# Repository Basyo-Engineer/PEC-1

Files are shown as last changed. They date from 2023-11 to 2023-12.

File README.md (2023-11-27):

# PEC-1
Hand made 8bitCPU, Prototype Experimental Computer No.1

## Picture
動いている様子．下記のSample Codeを動かしています．

F-tropnacAAZ7CA

## CPU Architecture

CPU Architecture drawio

## Command List
PEC-1で使用可能なコマンド一覧です．

GRx,GRyは汎用レジスタです．ImはImmidiate Data，すなわち即値データです．

スクリーンショット 2023-11-12 145332

## Machine Code
コマンドのマシン語対応表です．

xxやyyは，コマンドで指定したいレジスタ番号の二進数表示です．00(0)～11(3)番まで行けます．

[imdt]は即値データです．データ長は6bitです．

基本的に，オペコード部で各部の制御を行っています．なので，
ジャンプ命令などは仕様上レジスタの指定は冗長と扱うためオペランドはどう書いても問題ありません．
また，即値が「000000」となっているコマンドも，即値の入力は冗長です，

スクリーンショット 2023-11-12 145337

## Sample Code
サンプルコードです．掛け算と引き算を行うプログラムです．

スクリーンショット 2023-11-12 145524

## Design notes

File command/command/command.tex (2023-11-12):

\documentclass[lualatex,js=standard,hiresbb,openany]{bxjsarticle}
\usepackage{luatexja}
\usepackage{geometry}
\geometry{margin=5mm}

%数式
\usepackage{amsmath,amsfonts}
\usepackage{bm}
\usepackage{siunitx}
\usepackage{ulem}

%画像
\usepackage[dvipdfmx]{graphicx}
\usepackage{color}
\usepackage{subfigure}
\usepackage{float}
\usepackage{caption}
\usepackage{comment}

%枠付き文章
\usepackage{ascmac}

%章=chapter, 節=section, 小節=subseciton, 小小節=subsubsection
\begin{document}

\begin{table}[H]
 \begin{center}
  \begin{tabular}{cll}\hline
    命令種類 & ニーモニック & 説明 \\ 
    \hline \hline
    転送     & MOV  $\mathrm{GRx}$, $\mathrm{GRy}$        & $\mathrm{GRx}$ <- $\mathrm{GRy}$ \\ 
    転送     & MOV  $\mathrm{GRx}$, Im                    & $\mathrm{GRx}$ <- (Im)\\
    算術     & ADD  $\mathrm{GRx}$, $\mathrm{GRy}$        & $\mathrm{GRx}$ <- $\mathrm{GRx}$ + $\mathrm{GRy}$ \\ 
    算術     & ADD  $\mathrm{GRx}$, Im                    & $\mathrm{GRx}$ <- $\mathrm{GRx}$ + (Im) \\
    算術     & SUB  $\mathrm{GRx}$, $\mathrm{GRy}$        & $\mathrm{GRx}$ <- $\mathrm{GRx}$ - $\mathrm{GRy}$\\ 
    算術     & SUB  $\mathrm{GRx}$, Im                    & $\mathrm{GRx}$ <- $\mathrm{GRx}$ - (Im) \\
    論理     & NAND $\mathrm{GRx}$, $\mathrm{GRy}$        & $\mathrm{GRx}$ <- $\overline{\mathrm{GRx \cdot GRy}}$ \\
    論理     & NAND $\mathrm{GRx}$, Im                    & $\mathrm{GRx}$ <- $\overline{\mathrm{GRx \cdot Im}}$ \\
    条件分岐 & JMP  Im                                    & jump (Im) \\
    条件分岐 & JNO  Im                                    & jump (Im) if OverFlow Flag = 0 \\
    条件分岐 & JZE  Im                                    & jump (Im) if Zero Flag = 1 \\
    条件分岐 & JMI  Im                                    & jump (Im) if Sign Flag = 1\\
    条件分岐 & JPL  Im                                    & jump (Im) if Sign Flag = 0 \& Zero Flag = 0 \\
    その他   & IN   $\mathrm{GRx}$                        & $\mathrm{GRx}$ <- Input \\
    その他   & OUT  $\mathrm{GRx}$                        & $\mathrm{GRx}$ -> Output \\
    その他   & NOP                                        & なにもしない \\
     \hline
  \end{tabular}
  \label{tab:}
 \end{center}
\end{table}

\begin{table}[H]
 \begin{center}
  \begin{tabular}{lcccc}\hline
    命令                                & オペコード & オペランド1 & オペランド2 & 即値\\
    \hline \hline 
    MOV  $\mathrm{GRx}$, $\mathrm{GRy}$ &   0010    &   xx   &   yy   &    000000 \\
    MOV  $\mathrm{GRx}$, Im             &   0011    &   xx   &   00   &    [imdt] \\
    ADD  $\mathrm{GRx}$, $\mathrm{GRy}$ &   0100    &   xx   &   yy   &    000000 \\
    ADD  $\mathrm{GRx}$, Im             &   0101    &   xx   &   00   &    [imdt] \\
    SUB  $\mathrm{GRx}$, $\mathrm{GRy}$ &   0110    &   xx   &   yy   &    000000 \\
    SUB  $\mathrm{GRx}$, Im             &   0111    &   xx   &   00   &    [imdt] \\
    NAND $\mathrm{GRx}$, $\mathrm{GRy}$ &   1000    &   xx   &   yy   &    000000 \\
    NAND $\mathrm{GRx}$, Im             &   1001    &   xx   &   00   &    [imdt] \\
    JMP  Im                             &   0001    &   00   &   00   &    [imdt] \\
    JNO  Im                             &   1011    &   00   &   00   &    [imdt] \\
    JZE  Im                             &   1010    &   00   &   00   &    [imdt] \\
    JMI  Im                             &   1100    &   00   &   00   &    [imdt] \\
    JPL  Im                             &   1101    &   00   &   00   &    [imdt] \\
    IN   $\mathrm{GRx}$                 &   1110    &   xx   &   00   &    000000 \\
    OUT  $\mathrm{GRx}$                 &   1111    &   xx   &   00   &    000000 \\
    NOP                                 &   0000    &   00   &   00   &    000000 \\  
    \hline                          
  \end{tabular}
  \label{tab:}
 \end{center}
\end{table}

\begin{comment}
0:gr0, 1:gr1, 2:gr2, 3:gr3, 4:inp, 5:[imdt], 6:000000

\begin{table}[H]
 \begin{center}
  \caption{null}
  \begin{tabular}{|cccc|cc|cc|ccc|cccccccc|}\hline
    \multicolumn{4}{|c|}{opecord} & \multicolumn{4}{c|}{operand} & \multicolumn{3}{c|}{flag} &  \multicolumn{8}{c|}{出力}\\ \hline 
    op3 & op2 & op1 & op0 & ora1 & ora0 & orb1 & orb0 & ZF & OF & SF & sela & selb & ld0 & ld1 & ld2 & ld3 & ldo & ldp c \\ \hline
    0   & 0   & 1   & 0   & x    & x    & y    & y    &  X &  X &  X &   yy &  110 &   x  &  x &   x &   x &  1  &   1  \\  \hline
    0   & 0   & 1   & 1   & x    & x    & 0    & 0    &  X &  X &  X &  101 &  110 &   x  &  x &   x &   x &  1  &   1  \\ \hline
    0   & 1   & 0   & 0   & x    & x    & y    & y    &  X &  X &  X &   xx &   yy &   x  &  x &   x &   x &  1  &   1  \\ \hline
    0   & 1   & 0   & 1   & x    & x    & 0    & 0    &  X &  X &  X &   xx &  101 &   x  &  x &   x &   x &  1  &   1  \\ \hline
    0   & 1   & 1   & 0   & x    & x    & y    & y    &  X &  X &  X &   xx &   yy &   x  &  x &   x &   x &  1  &   1  \\ \hline
    0   & 1   & 1   & 1   & x    & x    & 0    & 0    &  X &  X &  X &   xx &  101 &   x  &  x &   x &   x &  1  &   1  \\ \hline
    1   & 0   & 0   & 0   & x    & x    & y    & y    &  X &  X &  X &   xx &   yy &   x  &  x &   x &   x &  1  &   1  \\ \hline
    1   & 0   & 0   & 1   & x    & x    & 0    & 0    &  X &  X &  X &   xx &  101 &   x  &  x &   x &   x &  1  &   1  \\ \hline
    0   & 0   & 0   & 1   & 0    & 0    & 0    & 0    &  X &  X &  X &  101 &  110 &   1  &  1 &   1 &   1 &  1  &   0  \\ \hline
    1   & 0   & 1   & 1   & 0    & 0    & 0    & 0    &  X &  0 &  X &  101 &  110 &   1  &  1 &   1 &   1 &  1  &   0  \\ \hline
    1   & 0   & 1   & 0   & 0    & 0    & 0    & 0    &  1 &  X &  X &  101 &  110 &   1  &  1 &   1 &   1 &  1  &   0  \\ \hline
    1   & 1   & 0   & 0   & 0    & 0    & 0    & 0    &  X &  X &  1 &  101 &  110 &   1  &  1 &   1 &   1 &  1  &   0  \\ \hline
    1   & 1   & 0   & 1   & 0    & 0    & 0    & 0    &  0 &  X &  0 &  101 &  110 &   1  &  1 &   1 &   1 &  1  &   0  \\ \hline
    1   & 1   & 1   & 0   & x    & x    & 0    & 0    &  X &  X &  X &  100 &  110 &   x  &  x &   x &   x &  1  &   1  \\ \hline
    1   & 1   & 1   & 1   & x    & x    & 0    & 0    &  X &  X &  X &   xx &  110 &   1  &  1 &   1 &   1 &  0  &   1  \\ \hline
    0   & 0   & 0   & 0   & 0    & 0    & 0    & 0    &  X &  X &  X &   00 &   00 &   1  &  1 &   1 &   1 &  1  &   1  \\ \hline
  \end{tabular}
  \label{tab:}
 \end{center}
\end{table}

\end{comment}

\end{document}

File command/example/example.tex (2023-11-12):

\documentclass[lualatex,js=standard,hiresbb,openany]{bxjsarticle}
\usepackage{luatexja}
\usepackage{geometry}
\geometry{margin=17mm}

%数式
\usepackage{amsmath,amsfonts}
\usepackage{bm}
\usepackage{siunitx}
\usepackage{ulem}
\usepackage{mathtools}

%画像
\usepackage[dvipdfmx]{graphicx}
\usepackage{color}
\usepackage{subfigure}
\usepackage{float}
\usepackage{caption}

%枠付き文章
\usepackage{ascmac}
\usepackage{comment}
\usepackage{url}

%松尾先生用
\begin{comment}
\usepackage{fancyhdr}
\pagestyle{fancy}
   \lhead{情報工学実験　第4章　デコーダおよび数字表示回路に関する実験}
   \chead{\empty} %ヘッダ中央
   \rhead{\empty} %ヘッダ右．コンパイルした日付を表示
   \lfoot{\empty} %フッタ左
   \cfoot{\thepage} %フッタ中央．ページ番号を表示
   \rfoot{\empty} %フッタ右
   \renewcommand{\headrulewidth}{0pt}

\end{comment}
\begin{document}

\center{掛け算プログラム(3 $\times$ 10と 4 $\times$ 3 を計算して，両結果を減算)}

\begin{table}[H]
  \begin{center}
   \begin{tabular}{lcccc}\hline
      アドレス & ニーモニック & マシンコード & コメント\\
      \hline \hline
      0 & MOV GR2, 0    & 0011 10 00 000000 & レジスタ2に0を代入\\
      1 & MOV GR0, 10   & 0011 00 00 001010 & レジスタ0に10を代入\\
      2 & SUB GR0, 0    & 0111 00 00 000000 & レジスタ0から0を減算\\
      3 & JZE at 7      & 1010 00 00 000010 & 前の計算結果でZero Flag = 1なら\\ &&&当該アドレスにジャンプ\\
      4 & ADD GR2, 3    & 0101 10 00 000011 & レジスタ2に3を加算\\
      5 & SUB GR0, 1    & 0111 00 00 000001 & レジスタ0から1を減算\\
      6 & JMP at 2      & 0001 00 00 000010 & 当該アドレスに強制ジャンプ\\
      7 & MOV GR3, 0    & 0011 11 00 000000 & レジスタ3に0を代入\\
      8 & MOV GR0, 3    & 0011 00 00 000011 & レジスタ0に3を代入\\
      9 & SUB GR0, 0    & 0111 00 00 000000 & レジスタ0から0を減算\\
     10 & JZE at 14     & 1010 00 00 001110 & 前の計算結果でZero Flag = 1なら\\ &&&当該アドレスにジャンプ\\
     11 & ADD GR3, 4    & 0101 11 00 000100 & レジスタ3に4を加算\\
     12 & SUB GR0, 1    & 0111 00 00 000001 & レジスタ0から1を減算\\
     13 & JMP at 9      & 0001 00 00 001001 & 当該アドレスに強制ジャンプ\\
     14 & SUB GR2, GR3  & 0110 10 11 000000 & GR2とGR3を減算 \\
     15 & MOV GR1, GR2  & 0010 01 10 000000 & GR1にGR2の値をコピー\\
     16 & OUT GR1       & 1111 01 00 000000 & 出力レジスタにGR1の値を出力\\
     17 & MOV GR0, 0    & 0011 00 00 000000 & レジスタ0に0を代入\\
     18 & MOV GR1, 0    & 0011 01 00 000000 & レジスタ1に0を代入\\
     19 & MOV GR2, 0    & 0011 10 00 000000 & レジスタ2に0を代入\\
     20 & MOV GR3, 0    & 0011 11 00 000000 & レジスタ3に0を代入\\
     21 & OUT GR0       & 1111 00 00 000000 & 出力レジスタにGR0の値を出力\\
     22 & JMP at 0      & 0001 00 00 000000 & 当該アドレスに強制ジャンプ\\

     \hline                          
   \end{tabular}
   \label{tab:}
  \end{center}
 \end{table}
 \newpage

 \center{符号付6bit 2進数対応表}
 \begin{table}[H]
  \begin{center}
   \begin{tabular}{|c|c|c|c|c|c|c|c|}\hline
      10進数 & 2進数 & & & 10進数 & 2進数 & & \\
      \hline
      0      & 000000 &  16 & 010000 0  &   -1      & 111111 &  -17 & 101111 \\
      1      & 000001 &  17 & 010001    &   -2      & 111110 &  -18 & 101110 \\     
      2      & 000010 &  18 & 010010    &   -3      & 111101 &  -19 & 101101 \\   
      3      & 000011 &  19 & 010011    &   -4      & 111100 &  -20 & 101100 \\   
      4      & 000100 &  20 & 010100    &   -5      & 111011 &  -21 & 101011 \\   
      5      & 000101 &  21 & 010101    &   -6      & 111010 &  -22 & 101010 \\   
      6      & 000110 &  22 & 010110    &   -7      & 111001 &  -23 & 101001 \\   
      7      & 000111 &  23 & 010111    &   -8      & 111000 &  -24 & 101000 \\   
      8      & 001000 &  24 & 011000    &   -9      & 110111 &  -25 & 100111 \\   
      9      & 001001 &  25 & 011001    &  -10      & 110110 &  -26 & 100110 \\   
     10      & 001010 &  26 & 011010    &  -11      & 110101 &  -27 & 100101 \\   
     11      & 001011 &  27 & 011011    &  -12      & 110100 &  -28 & 100100 \\   
     12      & 001100 &  28 & 011100    &  -13      & 110011 &  -29 & 100011 \\   
     13      & 001101 &  29 & 011101    &  -14      & 110010 &  -30 & 100010 \\   
     14      & 001110 &  30 & 011110    &  -15      & 110001 &  -31 & 100001 \\   
     15      & 001111 &  31 & 011111    &  -16      & 110000 &  -32 & 100000 \\   
     \hline
   \end{tabular}
   \label{tab:}
  \end{center}
 \end{table}

\end{document}

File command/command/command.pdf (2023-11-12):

命令種類 ニーモニック | 説明
転送 | MOV GRx, GRy | GRx <- GRy
転送 | MOV GRx, Im | GRx <- (Im)
算術 | ADD GRx, GRy | GRx <- GRx + GRy
算術 | ADD GRx, Im | GRx <- GRx + (Im)
算術 | SUB GRx, GRy | GRx <- GRx - GRy
算術 | SUB GRx, Im | GRx <- GRx - (Im)
論理 | NAND GRx, GRy | GRx <- GRx · GRy
論理 | NAND GRx, Im | GRx <- GRx · Im
条件分岐 JMP Im | jump (Im)
条件分岐 JNO Im | jump (Im) if OverFlow Flag = 0
条件分岐 JZE Im | jump (Im) if Zero Flag = 1
条件分岐 JMI Im | jump (Im) if Sign Flag = 1
条件分岐 JPL Im | jump (Im) if Sign Flag = 0 & Zero Flag = 0
その他 | IN GRx | GRx <- Input
その他 | OUT GRx | GRx -> Output
その他 | NOP | なにもしない
命令 | オペコード オペランド 1 オペランド 2 | 即値
MOV GRx, GRy | 0010 | xx | yy | 000000
MOV GRx, Im | 0011 | xx | 00 | [imdt]
ADD GRx, GRy | 0100 | xx | yy | 000000
ADD GRx, Im | 0101 | xx | 00 | [imdt]
SUB GRx, GRy | 0110 | xx | yy | 000000
SUB GRx, Im | 0111 | xx | 00 | [imdt]
NAND GRx, GRy | 1000 | xx | yy | 000000
NAND GRx, Im | 1001 | xx | 00 | [imdt]
JMP Im | 0001 | 00 | 00 | [imdt]
JNO Im | 1011 | 00 | 00 | [imdt]
JZE Im | 1010 | 00 | 00 | [imdt]
JMI Im | 1100 | 00 | 00 | [imdt]
JPL Im | 1101 | 00 | 00 | [imdt]
IN GRx | 1110 | xx | 00 | 000000
OUT GRx | 1111 | xx | 00 | 000000
NOP | 0000 | 00 | 00 | 000000

1

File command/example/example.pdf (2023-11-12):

掛け算プログラム (3 × 10 と 4 × 3 を計算して，両結果を減算)

アドレス | ニーモニック | マシンコード | コメント
0 | MOV GR2, 0 | 0011 10 00 000000 | レジスタ 2 に 0 を代入
1 | MOV GR0, 10 | 0011 00 00 001010 | レジスタ 0 に 10 を代入
2 | SUB GR0, 0 | 0111 00 00 000000 | レジスタ 0 から 0 を減算
3 | JZE at 7 | 1010 00 00 000010 前の計算結果で Zero Flag = 1 なら
| | | 当該アドレスにジャンプ
4 | ADD GR2, 3 | 0101 10 00 000011 | レジスタ 2 に 3 を加算
5 | SUB GR0, 1 | 0111 00 00 000001 | レジスタ 0 から 1 を減算
6 | JMP at 2 | 0001 00 00 000010 | 当該アドレスに強制ジャンプ
7 | MOV GR3, 0 | 0011 11 00 000000 | レジスタ 3 に 0 を代入
8 | MOV GR0, 3 | 0011 00 00 000011 | レジスタ 0 に 3 を代入
9 | SUB GR0, 0 | 0111 00 00 000000 | レジスタ 0 から 0 を減算
10 | JZE at 14 | 1010 00 00 001110 前の計算結果で Zero Flag = 1 なら
| | | 当該アドレスにジャンプ
11 | ADD GR3, 4 | 0101 11 00 000100 | レジスタ 3 に 4 を加算
12 | SUB GR0, 1 | 0111 00 00 000001 | レジスタ 0 から 1 を減算
13 | JMP at 9 | 0001 00 00 001001 | 当該アドレスに強制ジャンプ
14 | SUB GR2, GR3 0110 10 11 000000 | GR2 と GR3 を減算
15 | MOV GR1, GR2 0010 01 10 000000 | GR1 に GR2 の値をコピー
16 | OUT GR1 | 1111 01 00 000000 | 出力レジスタに GR1 の値を出力
17 | MOV GR0, 0 | 0011 00 00 000000 | レジスタ 0 に 0 を代入
18 | MOV GR1, 0 | 0011 01 00 000000 | レジスタ 1 に 0 を代入
19 | MOV GR2, 0 | 0011 10 00 000000 | レジスタ 2 に 0 を代入
20 | MOV GR3, 0 | 0011 11 00 000000 | レジスタ 3 に 0 を代入
21 | OUT GR0 | 1111 00 00 000000 | 出力レジスタに GR0 の値を出力
22 | JMP at 0 | 0001 00 00 000000 | 当該アドレスに強制ジャンプ

1

符号付 6bit 2 進数対応表

10 進数 | 2 進数 | | | 10 進数 | 2 進数
0 | 000000 | 16 | 010000 0 | -1 | 111111 | -17 | 101111
1 | 000001 | 17 | 010001 | -2 | 111110 | -18 | 101110
2 | 000010 | 18 | 010010 | -3 | 111101 | -19 | 101101
3 | 000011 | 19 | 010011 | -4 | 111100 | -20 | 101100
4 | 000100 | 20 | 010100 | -5 | 111011 | -21 | 101011
5 | 000101 | 21 | 010101 | -6 | 111010 | -22 | 101010
6 | 000110 | 22 | 010110 | -7 | 111001 | -23 | 101001
7 | 000111 | 23 | 010111 | -8 | 111000 | -24 | 101000
8 | 001000 | 24 | 011000 | -9 | 110111 | -25 | 100111
9 | 001001 | 25 | 011001 | -10 | 110110 | -26 | 100110
10 | 001010 | 26 | 011010 | -11 | 110101 | -27 | 100101
11 | 001011 | 27 | 011011 | -12 | 110100 | -28 | 100100
12 | 001100 | 28 | 011100 | -13 | 110011 | -29 | 100011
13 | 001101 | 29 | 011101 | -14 | 110010 | -30 | 100010
14 | 001110 | 30 | 011110 | -15 | 110001 | -31 | 100001
15 | 001111 | 31 | 011111 | -16 | 110000 | -32 | 100000

2

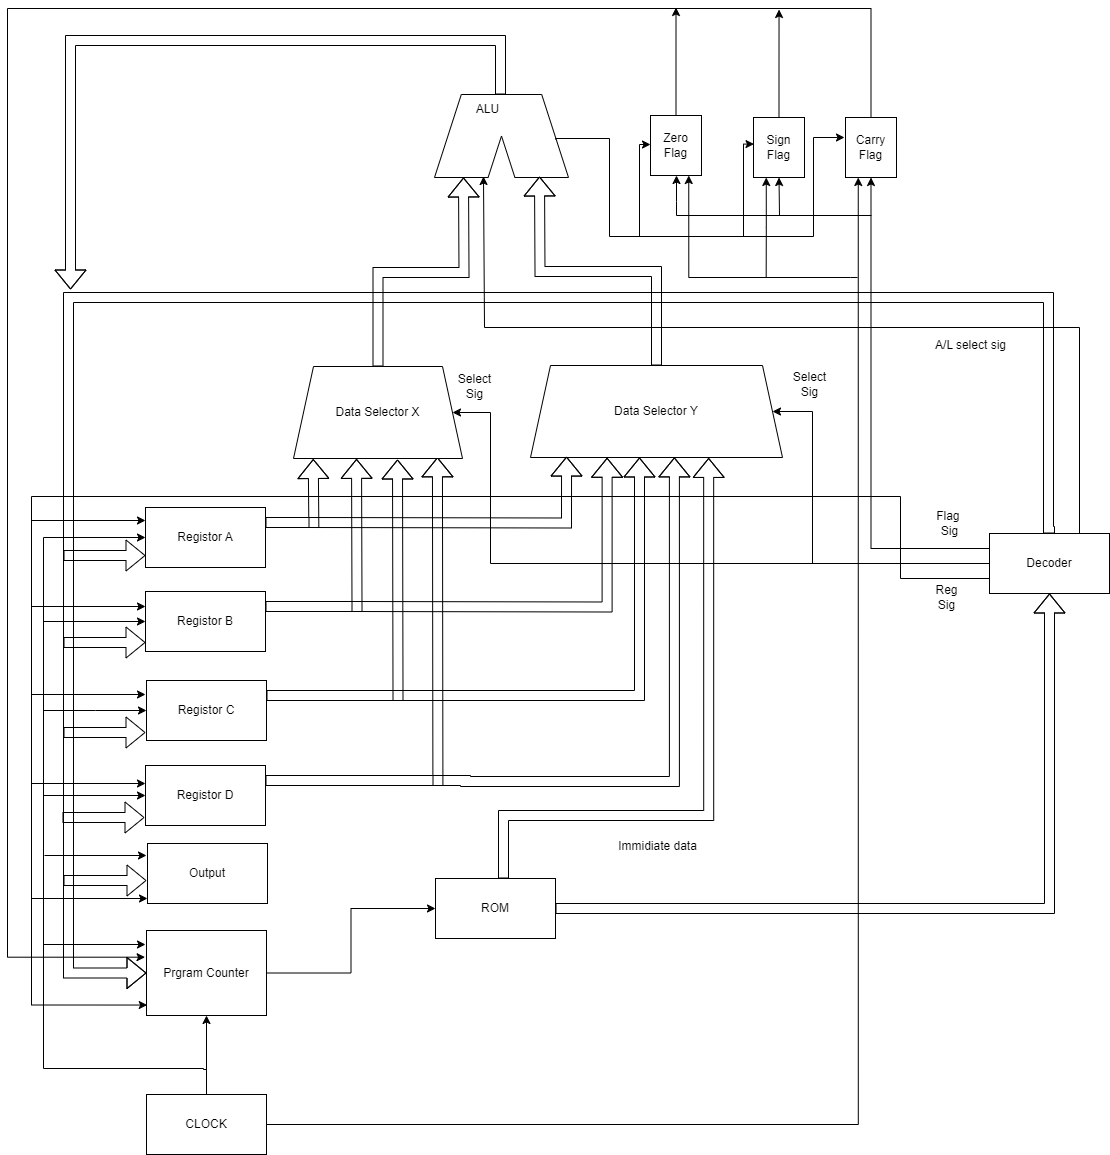
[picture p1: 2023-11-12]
architect/CPU Architecture.drawio.png

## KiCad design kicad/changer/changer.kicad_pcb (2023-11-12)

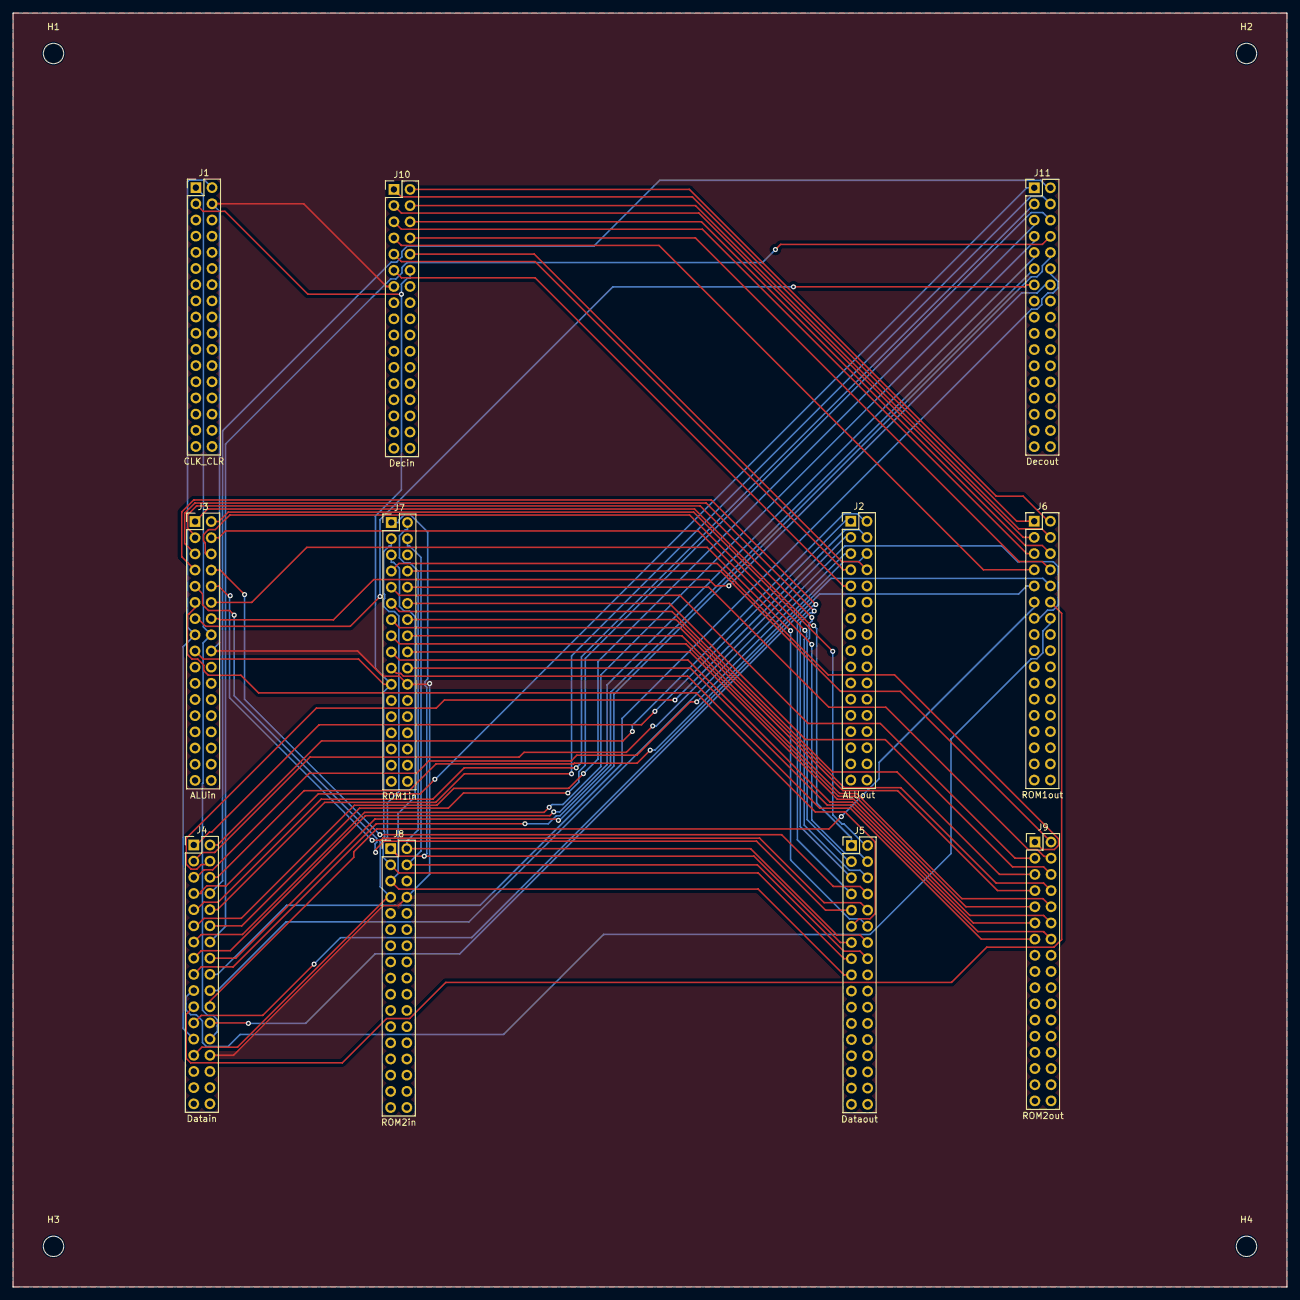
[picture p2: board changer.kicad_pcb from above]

Board: 2 copper layers, 200.0 x 200.0 mm, 15 parts (0 on the bottom side), 72 nets.

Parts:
H1, H2, H3, H4: MountingHole; MountingHole_3.2mm_M3
J1: CLK_CLR; PinHeader_2x17_P2.54mm_Vertical
J2: ALUout; PinHeader_2x17_P2.54mm_Vertical
J3: ALUin; PinHeader_2x17_P2.54mm_Vertical
J4: Datain; PinHeader_2x17_P2.54mm_Vertical
J5: Dataout; PinHeader_2x17_P2.54mm_Vertical
J6: ROM1out; PinHeader_2x17_P2.54mm_Vertical
J7: ROM1in; PinHeader_2x17_P2.54mm_Vertical
J8: ROM2in; PinHeader_2x17_P2.54mm_Vertical
J9: ROM2out; PinHeader_2x17_P2.54mm_Vertical
J10: Decin; PinHeader_2x17_P2.54mm_Vertical
J11: Decout; PinHeader_2x17_P2.54mm_Vertical

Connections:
2Im0: J7.20, J9.14
2Im1: J7.19, J9.13
2Im2: J7.18, J9.12
2Im3: J7.17, J9.11
2Im4: J7.16, J9.10
2Im5: J7.15, J9.9
2oc0: J7.10, J9.4
2oc1: J7.9, J9.3
2oc2: J7.8, J9.2
2oc3: J7.7, J9.1
2ol0: J7.14, J9.8
2ol1: J7.13, J9.7
2ol2: J7.12, J9.6
2ol3: J7.11, J9.5
+5V: J1.3, J3.17, J4.27, J7.21, J8.7, J10.12
+/-: J3.13, J11.13
A0: J3.1, J5.1
A1: J3.2, J5.2
A2: J3.3, J5.3
A3: J3.4, J5.4
A4: J3.5, J5.5
A5: J3.6, J5.6
A/L: J3.14, J11.14
B0: J3.7, J5.7
B1: J3.8, J5.8
B2: J3.9, J5.9
B3: J3.10, J5.10
B4: J3.11, J5.11
B5: J3.12, J5.12
CLK: J1.1, J3.16, J4.26
CLR: J1.2, J3.15, J4.25
GND: J1.4, J3.18, J4.28, J7.22, J8.8, J10.13
Im0: J4.19, J6.14
Im1: J4.20, J6.13
Im2: J4.21, J6.12
Im3: J4.22, J6.11
Im4: J4.23, J6.10
Im5: J4.24, J6.9
LD0: J4.13, J11.7
LD1: J4.14, J11.8
LD2: J4.15, J11.9
LD3: J4.16, J11.10
LDo: J4.17, J11.11
LDpc: J4.18, J11.12
OFR: J2.8, J10.10
SFR: J2.9, J10.11
Y0: J2.1, J4.1
Y1: J2.2, J4.2
Y2: J2.3, J4.3
Y3: J2.4, J4.4
Y4: J2.5, J4.5
Y5: J2.6, J4.6
ZFR: J2.7, J10.9
oc0: J6.4, J10.4
oc1: J6.3, J10.3
oc2: J6.2, J10.2
oc3: J6.1, J10.1
ol0: J6.8, J10.8
ol1: J6.7, J10.7
ol2: J6.6, J10.6
ol3: J6.5, J10.5
pc0: J5.13, J7.1, J8.1
pc1: J5.14, J7.2, J8.2
pc2: J5.15, J7.3, J8.3
pc3: J5.16, J7.4, J8.4
pc4: J5.17, J7.5, J8.5
sela0: J4.7, J11.1
sela1: J4.8, J11.2
sela2: J4.9, J11.3
selb0: J4.10, J11.4
selb1: J4.11, J11.5
selb2: J4.12, J11.6

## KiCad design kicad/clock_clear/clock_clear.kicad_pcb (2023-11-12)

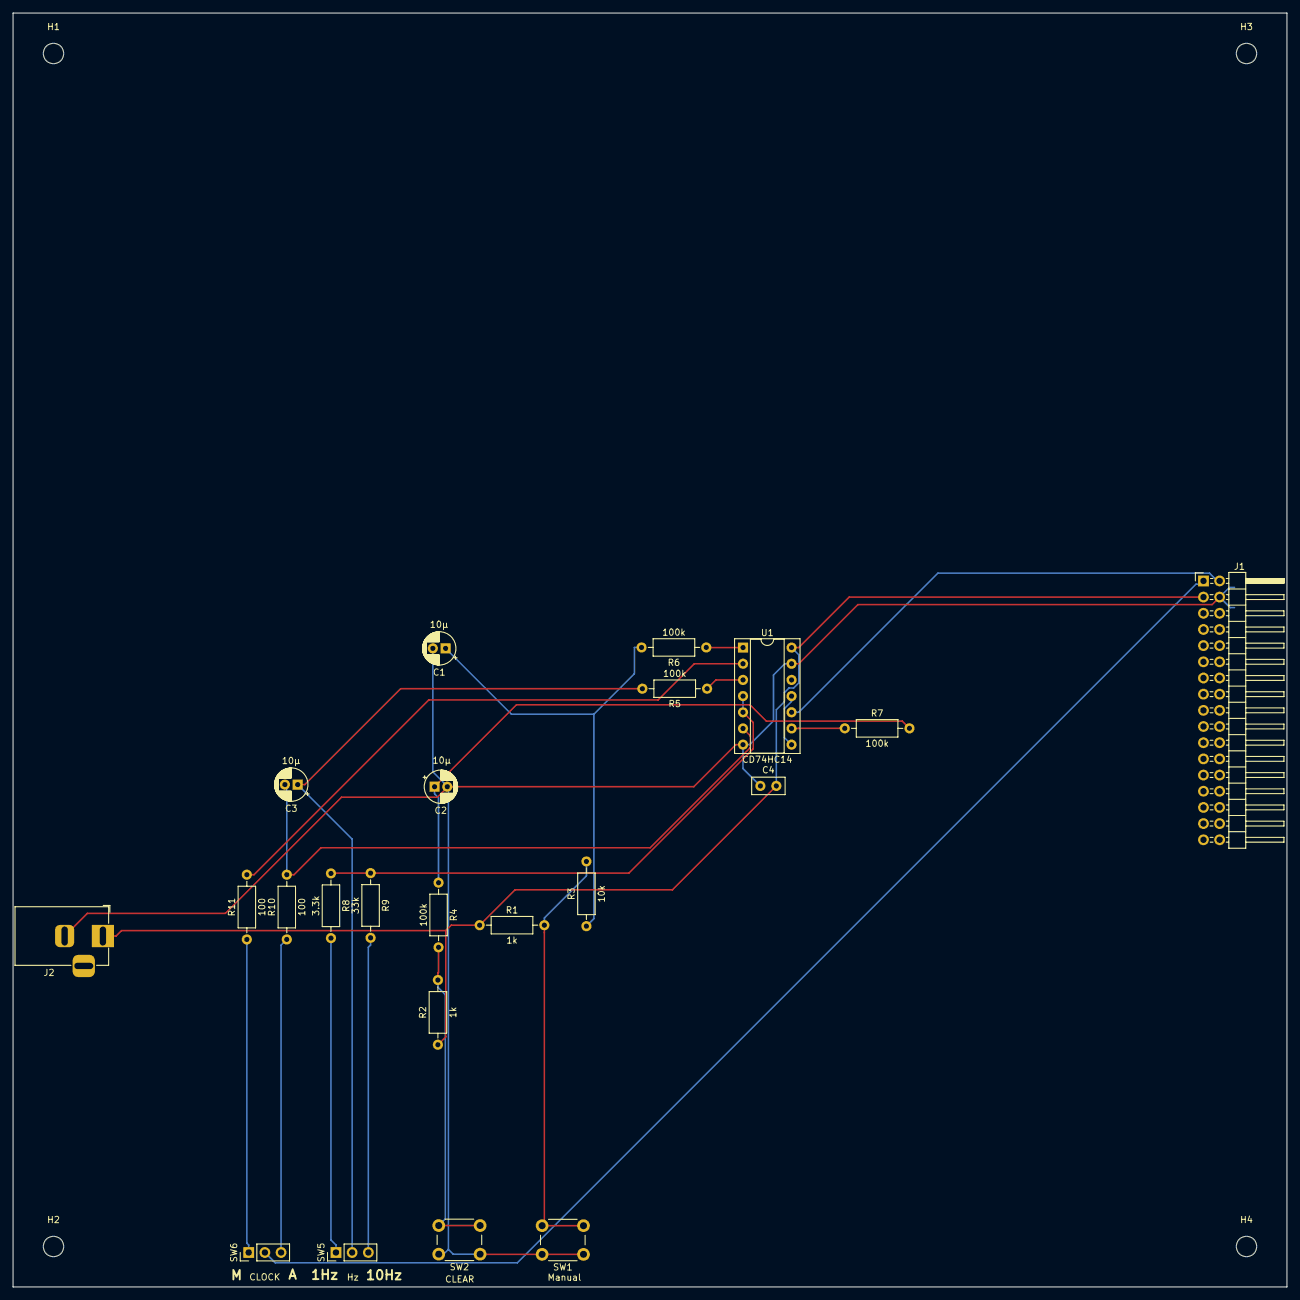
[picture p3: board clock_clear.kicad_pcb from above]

Board: 2 copper layers, 200.0 x 200.0 mm, 26 parts (0 on the bottom side), 20 nets.

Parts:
C1, C2, C3: 10μ; CP_Radial_D5.0mm_P2.00mm
C4: 0.1μ; C_Disc_D5.0mm_W2.5mm_P2.50mm
H1, H2, H3, H4: MountingHole; MountingHole_3.2mm_M3
J1: Conn_01x34_Pin; PinHeader_2x17_P2.54mm_Horizontal
J2: Barrel_Jack; BarrelJack_Horizontal
R1, R2: 1k; R_Axial_DIN0207_L6.3mm_D2.5mm_P10.16mm_Horizontal
R3: 10k; R_Axial_DIN0207_L6.3mm_D2.5mm_P10.16mm_Horizontal
R4, R5, R6, R7: 100k; R_Axial_DIN0207_L6.3mm_D2.5mm_P10.16mm_Horizontal
R8: 3.3k; R_Axial_DIN0207_L6.3mm_D2.5mm_P10.16mm_Horizontal
R9: 33k; R_Axial_DIN0207_L6.3mm_D2.5mm_P10.16mm_Horizontal
R10, R11: 100; R_Axial_DIN0207_L6.3mm_D2.5mm_P10.16mm_Horizontal
SW1: Manual; SW_PUSH_6mm
SW2: CLEAR; SW_PUSH_6mm
SW5: Hz; PinHeader_1x03_P2.54mm_Vertical
SW6: CLOCK; PinHeader_1x03_P2.54mm_Vertical
U1: CD74HC14; DIP-14_W7.62mm_Socket

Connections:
+5V: C4.2, J1.3, J2.1, R1.1, R2.1, U1.14 (Vcc)
CLK: J1.1, SW6.2 (B)
CLR: J1.2, U1.10
GND: C1.2, C2.2, C4.1, J1.4, J2.2, SW1.1, SW2.1, U1.7 (GND), U1.13
unnamed: C1.1, R3.1, R6.2
unnamed: C2.1, R4.1, R7.2
unnamed: C3.2, R10.2, U1.6
unnamed: R1.2, R3.2, SW1.2
unnamed: R2.2, R4.2, SW2.2
unnamed: R5.1, U1.3
unnamed: R6.1, U1.1
unnamed: R7.1, U1.9
unnamed: R8.1, R9.1, U1.4, U1.5
unnamed: R11.2, U1.2
unnamed: R8.2, SW5.1 (A)
unnamed: C3.1, R5.2, SW5.2 (B)
unnamed: R9.2, SW5.3 (C)
unnamed: R11.1, SW6.1 (A)
unnamed: R10.1, SW6.3 (C)
unnamed: U1.8, U1.11

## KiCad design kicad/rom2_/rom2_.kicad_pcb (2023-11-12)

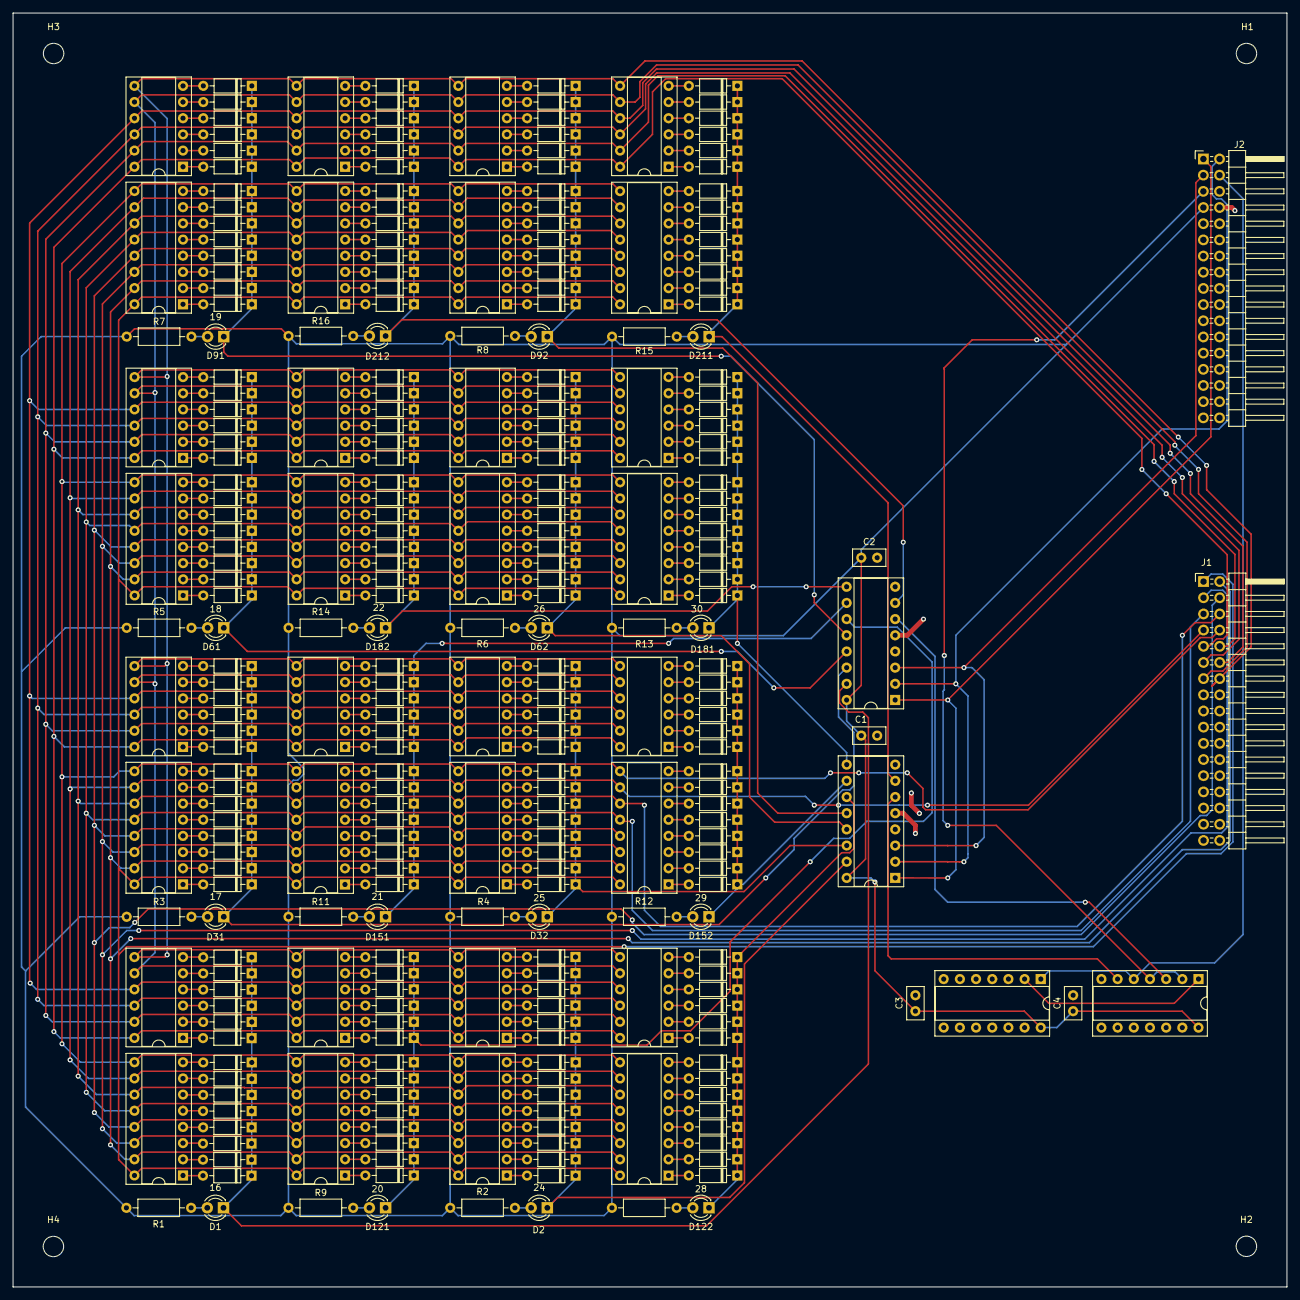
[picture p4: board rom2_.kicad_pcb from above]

Board: 2 copper layers, 200.0 x 200.0 mm, 302 parts (0 on the bottom side), 280 nets.

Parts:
C1, C2, C3, C4: 0.1μ; C_Disc_D5.0mm_W2.5mm_P2.50mm
D1: 16; LED_D3.0mm
D2: 24; LED_D3.0mm
D3, D4, D5, D6, D7, D8, D9, D10, D11, D12, D13, D14, D15, D16, D17, D18, D19, D20, D21, D22, D23, D24, D25, D26, D27, D28, D29, D30, D33, D34, D35, D36, D37, D38, D39, D40, D41, D42, D43, D44, D45, D46, D47, D48, D49, D50, D51, D52, D53, D54, D55, D56, D57, D58, D59, D60, D63, D64, D65, D66, D67, D68, D69, D70, D71, D72, D73, D74, D75, D76, D77, D78, D79, D80, D81, D82, D83, D84, D85, D86, D87, D88, D89, D90, D93, D94, D95, D96, D97, D98, D99, D100, D101, D102, D103, D104, D105, D106, D107, D108, D109, D110, D111, D112, D113, D114, D115, D116, D117, D118, D119, D120, D123, D124, D125, D126, D127, D128, D129, D130, D131, D132, D133, D134, D135, D136, D137, D138, D139, D140, D141, D142, D143, D144, D145, D146, D147, D148, D149, D150, D153, D154, D155, D156, D157, D158, D159, D160, D161, D162, D163, D164, D165, D166, D167, D168, D169, D170, D171, D172, D173, D174, D175, D176, D177, D178, D179, D180, D183, D184, D185, D186, D187, D188, D189, D190, D191, D192, D193, D194, D195, D196, D197, D198, D199, D200, D201, D202, D203, D204, D205, D206, D207, D208, D209, D210, D213, D214, D215, D216, D217, D218, D219, D220, D221, D222, D223, D224, D225, D226, D227, D228, D229, D230, D231, D232, D233, D234, D235, D236, D237, D238, D239, D240: 1N4148; D_DO-35_SOD27_P7.62mm_Horizontal
D31: 17; LED_D3.0mm
D32: 25; LED_D3.0mm
D61: 18; LED_D3.0mm
D62: 26; LED_D3.0mm
D91: 19; LED_D3.0mm
D92: 27; LED_D3.0mm
D121: 20; LED_D3.0mm
D122: 28; LED_D3.0mm
D151: 21; LED_D3.0mm
D152: 29; LED_D3.0mm
D181: 30; LED_D3.0mm
D182: 22; LED_D3.0mm
D211: 31; LED_D3.0mm
D212: 23; LED_D3.0mm
H1, H2, H3, H4: MountingHole; MountingHole_3.2mm_M3
J1, J2: Conn_01x34_Pin; PinHeader_2x17_P2.54mm_Horizontal
R1, R2, R3, R4, R5, R6, R7, R8, R9, R10, R11, R12, R13, R14, R15, R16: 1K; R_Axial_DIN0207_L6.3mm_D2.5mm_P10.16mm_Horizontal
SW1, SW2, SW5, SW6, SW9, SW10, SW13, SW14, SW17, SW18, SW21, SW22, SW25, SW26, SW29, SW30: SW_DIP_x08; DIP-16_W7.62mm_Socket
SW3, SW4, SW7, SW8, SW11, SW12, SW15, SW16, SW19, SW20, SW23, SW24, SW27, SW28, SW31, SW32: SW_DIP_x06; DIP-12_W7.62mm_Socket
U1: CD74HC14; DIP-14_W7.62mm_Socket
U2: CD74HC08; DIP-14_W7.62mm_Socket
U3, U4: 74HC138; DIP-16_W7.62mm_Socket

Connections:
2Im0: J1.14, SW3.7, SW4.7, SW7.7, SW8.7, SW11.7, SW12.7, SW15.7, SW16.7, SW19.7, SW20.7, SW23.7, SW24.7, SW27.7, SW28.7, SW31.7, SW32.7
2Im1: J1.13, SW3.8, SW4.8, SW7.8, SW8.8, SW11.8, SW12.8, SW15.8, SW16.8, SW19.8, SW20.8, SW23.8, SW24.8, SW27.8, SW28.8, SW31.8, SW32.8
2Im2: J1.12, SW3.9, SW4.9, SW7.9, SW8.9, SW11.9, SW12.9, SW15.9, SW16.9, SW19.9, SW20.9, SW23.9, SW24.9, SW27.9, SW28.9, SW31.9, SW32.9
2Im3: J1.11, SW3.10, SW4.10, SW7.10, SW8.10, SW11.10, SW12.10, SW15.10, SW16.10, SW19.10, SW20.10, SW23.10, SW24.10, SW27.10, SW28.10, SW31.10, SW32.10
2Im4: J1.10, SW3.11, SW4.11, SW7.11, SW8.11, SW11.11, SW12.11, SW15.11, SW16.11, SW19.11, SW20.11, SW23.11, SW24.11, SW27.11, SW28.11, SW31.11, SW32.11
2Im5: J1.9, SW3.12, SW4.12, SW7.12, SW8.12, SW11.12, SW12.12, SW15.12, SW16.12, SW19.12, SW20.12, SW23.12, SW24.12, SW27.12, SW28.12, SW31.12, SW32.12
2oc0: J1.4, SW1.13, SW2.13, SW5.13, SW6.13, SW9.13, SW10.13, SW13.13, SW14.13, SW17.13, SW18.13, SW21.13, SW22.13, SW25.13, SW26.13, SW29.13, SW30.13
2oc1: J1.3, SW1.14, SW2.14, SW5.14, SW6.14, SW9.14, SW10.14, SW13.14, SW14.14, SW17.14, SW18.14, SW21.14, SW22.14, SW25.14, SW26.14, SW29.14, SW30.14
2oc2: J1.2, SW1.15, SW2.15, SW5.15, SW6.15, SW9.15, SW10.15, SW13.15, SW14.15, SW17.15, SW18.15, SW21.15, SW22.15, SW25.15, SW26.15, SW29.15, SW30.15
2oc3: J1.1, SW1.16, SW2.16, SW5.16, SW6.16, SW9.16, SW10.16, SW13.16, SW14.16, SW17.16, SW18.16, SW21.16, SW22.16, SW25.16, SW26.16, SW29.16, SW30.16
2ol0: J1.8, SW1.9, SW2.9, SW5.9, SW6.9, SW9.9, SW10.9, SW13.9, SW14.9, SW17.9, SW18.9, SW21.9, SW22.9, SW25.9, SW26.9, SW29.9, SW30.9
2ol1: J1.7, SW1.10, SW2.10, SW5.10, SW6.10, SW9.10, SW10.10, SW13.10, SW14.10, SW17.10, SW18.10, SW21.10, SW22.10, SW25.10, SW26.10, SW29.10, SW30.10
2ol2: J1.6, SW1.11, SW2.11, SW5.11, SW6.11, SW9.11, SW10.11, SW13.11, SW14.11, SW17.11, SW18.11, SW21.11, SW22.11, SW25.11, SW26.11, SW29.11, SW30.11
2ol3: J1.5, SW1.12, SW2.12, SW5.12, SW6.12, SW9.12, SW10.12, SW13.12, SW14.12, SW17.12, SW18.12, SW21.12, SW22.12, SW25.12, SW26.12, SW29.12, SW30.12
+5V: C1.1, C2.1, C3.1, C4.1, J2.7, R1.1, R2.1, R3.1, R4.1, R5.1, R6.1, R7.1, R8.1, R9.1, R10.1, R11.1, R12.1, R13.1, R14.1, R15.1, R16.1, U1.14 (Vcc), U2.14 (Vcc), U3.16 (VCC), U4.16 (VCC)
GND: C1.2, C2.2, C3.2, C4.2, J2.8, U1.3, U1.5, U1.7 (GND), U1.9, U1.11, U1.13, U2.7 (GND), U2.9, U2.10, U2.12, U2.13, U3.4 (~E0), U3.5 (~E1), U3.8 (GND), U4.4 (~E0), U4.5 (~E1), U4.8 (GND)
unnamed: D1.2 (A), R1.2
unnamed: D1.1 (K), D3.1 (K), D5.1 (K), D7.1 (K), D9.1 (K), D11.1 (K), D13.1 (K), D15.1 (K), D17.1 (K), D19.1 (K), D21.1 (K), D23.1 (K), D25.1 (K), D27.1 (K), D29.1 (K), U3.15 (~Y0)
unnamed: D2.2 (A), R2.2
unnamed: D3.2 (A), SW1.1
unnamed: D4.2 (A), SW2.1
unnamed: D5.2 (A), SW1.2
unnamed: D6.2 (A), SW2.2
unnamed: D7.2 (A), SW1.3
unnamed: D8.2 (A), SW2.3
unnamed: D9.2 (A), SW1.4
unnamed: D10.2 (A), SW2.4
unnamed: D2.1 (K), D4.1 (K), D6.1 (K), D8.1 (K), D10.1 (K), D12.1 (K), D14.1 (K), D16.1 (K), D18.1 (K), D20.1 (K), D22.1 (K), D24.1 (K), D26.1 (K), D28.1 (K), D30.1 (K), U4.15 (~Y0)
unnamed: D11.2 (A), SW1.5
unnamed: D12.2 (A), SW2.5
unnamed: D13.2 (A), SW1.6
unnamed: D14.2 (A), SW2.6
unnamed: D15.2 (A), SW1.7
unnamed: D16.2 (A), SW2.7
unnamed: D17.2 (A), SW1.8
unnamed: D18.2 (A), SW2.8
unnamed: D19.2 (A), SW3.1
unnamed: D20.2 (A), SW4.1
unnamed: D21.2 (A), SW3.2
unnamed: D22.2 (A), SW4.2
unnamed: D23.2 (A), SW3.3
unnamed: D24.2 (A), SW4.3
unnamed: D25.2 (A), SW3.4
unnamed: D26.2 (A), SW4.4
unnamed: D27.2 (A), SW3.5
unnamed: D28.2 (A), SW4.5
unnamed: D29.2 (A), SW3.6
unnamed: D30.2 (A), SW4.6
unnamed: D31.2 (A), R3.2
unnamed: D31.1 (K), D33.1 (K), D35.1 (K), D37.1 (K), D39.1 (K), D41.1 (K), D43.1 (K), D45.1 (K), D47.1 (K), D49.1 (K), D51.1 (K), D53.1 (K), D55.1 (K), D57.1 (K), D59.1 (K), U3.14 (~Y1)
unnamed: D32.2 (A), R4.2
unnamed: D32.1 (K), D34.1 (K), D36.1 (K), D38.1 (K), D40.1 (K), D42.1 (K), D44.1 (K), D46.1 (K), D48.1 (K), D50.1 (K), D52.1 (K), D54.1 (K), D56.1 (K), D58.1 (K), D60.1 (K), U4.14 (~Y1)
unnamed: D33.2 (A), SW5.1
unnamed: D34.2 (A), SW6.1
unnamed: D35.2 (A), SW5.2
unnamed: D36.2 (A), SW6.2
unnamed: D37.2 (A), SW5.3
unnamed: D38.2 (A), SW6.3
unnamed: D39.2 (A), SW5.4
unnamed: D40.2 (A), SW6.4
unnamed: D41.2 (A), SW5.5
unnamed: D42.2 (A), SW6.5
unnamed: D43.2 (A), SW5.6
unnamed: D44.2 (A), SW6.6
unnamed: D45.2 (A), SW5.7
unnamed: D46.2 (A), SW6.7
unnamed: D47.2 (A), SW5.8
unnamed: D48.2 (A), SW6.8
unnamed: D49.2 (A), SW7.1
unnamed: D50.2 (A), SW8.1
unnamed: D51.2 (A), SW7.2
unnamed: D52.2 (A), SW8.2
unnamed: D53.2 (A), SW7.3
unnamed: D54.2 (A), SW8.3
unnamed: D55.2 (A), SW7.4
unnamed: D56.2 (A), SW8.4
unnamed: D57.2 (A), SW7.5
unnamed: D58.2 (A), SW8.5
unnamed: D59.2 (A), SW7.6
unnamed: D60.2 (A), SW8.6
unnamed: D61.2 (A), R5.2
unnamed: D61.1 (K), D63.1 (K), D65.1 (K), D67.1 (K), D69.1 (K), D71.1 (K), D73.1 (K), D75.1 (K), D77.1 (K), D79.1 (K), D81.1 (K), D83.1 (K), D85.1 (K), D87.1 (K), D89.1 (K), U3.13 (~Y2)
unnamed: D62.2 (A), R6.2
unnamed: D62.1 (K), D64.1 (K), D66.1 (K), D68.1 (K), D70.1 (K), D72.1 (K), D74.1 (K), D76.1 (K), D78.1 (K), D80.1 (K), D82.1 (K), D84.1 (K), D86.1 (K), D88.1 (K), D90.1 (K), U4.13 (~Y2)
unnamed: D63.2 (A), SW9.1
unnamed: D64.2 (A), SW10.1
unnamed: D65.2 (A), SW9.2
unnamed: D66.2 (A), SW10.2
unnamed: D67.2 (A), SW9.3
unnamed: D68.2 (A), SW10.3
unnamed: D69.2 (A), SW9.4
unnamed: D70.2 (A), SW10.4
unnamed: D71.2 (A), SW9.5
unnamed: D72.2 (A), SW10.5
unnamed: D73.2 (A), SW9.6
unnamed: D74.2 (A), SW10.6
unnamed: D75.2 (A), SW9.7
unnamed: D76.2 (A), SW10.7
unnamed: D77.2 (A), SW9.8
unnamed: D78.2 (A), SW10.8
unnamed: D79.2 (A), SW11.1
unnamed: D80.2 (A), SW12.1
unnamed: D81.2 (A), SW11.2
unnamed: D82.2 (A), SW12.2
unnamed: D83.2 (A), SW11.3
unnamed: D84.2 (A), SW12.3
unnamed: D85.2 (A), SW11.4
unnamed: D86.2 (A), SW12.4
unnamed: D87.2 (A), SW11.5
unnamed: D88.2 (A), SW12.5
unnamed: D89.2 (A), SW11.6
unnamed: D90.2 (A), SW12.6
unnamed: D91.2 (A), R7.2
unnamed: D92.2 (A), R8.2
unnamed: D93.2 (A), SW13.1
unnamed: D94.2 (A), SW14.1
unnamed: D95.2 (A), SW13.2
unnamed: D96.2 (A), SW14.2
unnamed: D97.2 (A), SW13.3
unnamed: D98.2 (A), SW14.3
unnamed: D99.2 (A), SW13.4
unnamed: D100.2 (A), SW14.4
unnamed: D92.1 (K), D94.1 (K), D96.1 (K), D98.1 (K), D100.1 (K), D102.1 (K), D104.1 (K), D106.1 (K), D108.1 (K), D110.1 (K), D112.1 (K), D114.1 (K), D116.1 (K), D118.1 (K), D120.1 (K), U4.12 (~Y3)
unnamed: D101.2 (A), SW13.5
unnamed: D91.1 (K), D93.1 (K), D95.1 (K), D97.1 (K), D99.1 (K), D101.1 (K), D103.1 (K), D105.1 (K), D107.1 (K), D109.1 (K), D111.1 (K), D113.1 (K), D115.1 (K), D117.1 (K), D119.1 (K), U3.12 (~Y3)
unnamed: D102.2 (A), SW14.5
unnamed: D103.2 (A), SW13.6
unnamed: D104.2 (A), SW14.6
unnamed: D105.2 (A), SW13.7
unnamed: D106.2 (A), SW14.7
unnamed: D107.2 (A), SW13.8
unnamed: D108.2 (A), SW14.8
unnamed: D109.2 (A), SW15.1
unnamed: D110.2 (A), SW16.1
unnamed: D111.2 (A), SW15.2
unnamed: D112.2 (A), SW16.2
unnamed: D113.2 (A), SW15.3
unnamed: D114.2 (A), SW16.3
unnamed: D115.2 (A), SW15.4
unnamed: D116.2 (A), SW16.4
unnamed: D117.2 (A), SW15.5
unnamed: D118.2 (A), SW16.5
unnamed: D119.2 (A), SW15.6
unnamed: D120.2 (A), SW16.6
unnamed: D121.2 (A), R9.2
unnamed: D121.1 (K), D123.1 (K), D125.1 (K), D127.1 (K), D129.1 (K), D131.1 (K), D133.1 (K), D135.1 (K), D137.1 (K), D139.1 (K), D141.1 (K), D143.1 (K), D145.1 (K), D147.1 (K), D149.1 (K), U3.11 (~Y4)
unnamed: D122.2 (A), R10.2
unnamed: D122.1 (K), D124.1 (K), D126.1 (K), D128.1 (K), D130.1 (K), D132.1 (K), D134.1 (K), D136.1 (K), D138.1 (K), D140.1 (K), D142.1 (K), D144.1 (K), D146.1 (K), D148.1 (K), D150.1 (K), U4.11 (~Y4)
unnamed: D123.2 (A), SW17.1
unnamed: D124.2 (A), SW18.1
unnamed: D125.2 (A), SW17.2
unnamed: D126.2 (A), SW18.2
unnamed: D127.2 (A), SW17.3
unnamed: D128.2 (A), SW18.3
unnamed: D129.2 (A), SW17.4
unnamed: D130.2 (A), SW18.4
unnamed: D131.2 (A), SW17.5
unnamed: D132.2 (A), SW18.5
unnamed: D133.2 (A), SW17.6
unnamed: D134.2 (A), SW18.6
unnamed: D135.2 (A), SW17.7
unnamed: D136.2 (A), SW18.7
unnamed: D137.2 (A), SW17.8
unnamed: D138.2 (A), SW18.8
unnamed: D139.2 (A), SW19.1
unnamed: D140.2 (A), SW20.1
unnamed: D141.2 (A), SW19.2
unnamed: D142.2 (A), SW20.2
unnamed: D143.2 (A), SW19.3
unnamed: D144.2 (A), SW20.3
unnamed: D145.2 (A), SW19.4
unnamed: D146.2 (A), SW20.4
unnamed: D147.2 (A), SW19.5
unnamed: D148.2 (A), SW20.5
unnamed: D149.2 (A), SW19.6
unnamed: D150.2 (A), SW20.6
unnamed: D151.2 (A), R11.2
unnamed: D151.1 (K), D153.1 (K), D155.1 (K), D157.1 (K), D159.1 (K), D161.1 (K), D163.1 (K), D165.1 (K), D167.1 (K), D169.1 (K), D171.1 (K), D173.1 (K), D175.1 (K), D177.1 (K), D179.1 (K), U3.10 (~Y5)
unnamed: D152.2 (A), R12.2
unnamed: D152.1 (K), D154.1 (K), D156.1 (K), D158.1 (K), D160.1 (K), D162.1 (K), D164.1 (K), D166.1 (K), D168.1 (K), D170.1 (K), D172.1 (K), D174.1 (K), D176.1 (K), D178.1 (K), D180.1 (K), U4.10 (~Y5)
unnamed: D153.2 (A), SW21.1
unnamed: D154.2 (A), SW22.1
unnamed: D155.2 (A), SW21.2
unnamed: D156.2 (A), SW22.2
unnamed: D157.2 (A), SW21.3
unnamed: D158.2 (A), SW22.3
unnamed: D159.2 (A), SW21.4
unnamed: D160.2 (A), SW22.4
unnamed: D161.2 (A), SW21.5
unnamed: D162.2 (A), SW22.5
unnamed: D163.2 (A), SW21.6
unnamed: D164.2 (A), SW22.6
unnamed: D165.2 (A), SW21.7
unnamed: D166.2 (A), SW22.7
unnamed: D167.2 (A), SW21.8
unnamed: D168.2 (A), SW22.8
unnamed: D169.2 (A), SW23.1
unnamed: D170.2 (A), SW24.1
unnamed: D171.2 (A), SW23.2
unnamed: D172.2 (A), SW24.2
unnamed: D173.2 (A), SW23.3
unnamed: D174.2 (A), SW24.3
unnamed: D175.2 (A), SW23.4
unnamed: D176.2 (A), SW24.4
unnamed: D177.2 (A), SW23.5
unnamed: D178.2 (A), SW24.5
unnamed: D179.2 (A), SW23.6
unnamed: D180.2 (A), SW24.6
unnamed: D181.2 (A), R13.2
unnamed: D181.1 (K), D183.1 (K), D185.1 (K), D187.1 (K), D189.1 (K), D191.1 (K), D193.1 (K), D195.1 (K), D197.1 (K), D199.1 (K), D201.1 (K), D203.1 (K), D205.1 (K), D207.1 (K), D209.1 (K), U4.9 (~Y6)
unnamed: D182.2 (A), R14.2
unnamed: D182.1 (K), D184.1 (K), D186.1 (K), D188.1 (K), D190.1 (K), D192.1 (K), D194.1 (K), D196.1 (K), D198.1 (K), D200.1 (K), D202.1 (K), D204.1 (K), D206.1 (K), D208.1 (K), D210.1 (K), U3.9 (~Y6)
unnamed: D183.2 (A), SW25.1
unnamed: D184.2 (A), SW26.1
unnamed: D185.2 (A), SW25.2
unnamed: D186.2 (A), SW26.2
unnamed: D187.2 (A), SW25.3
unnamed: D188.2 (A), SW26.3
unnamed: D189.2 (A), SW25.4
unnamed: D190.2 (A), SW26.4
unnamed: D191.2 (A), SW25.5
unnamed: D192.2 (A), SW26.5
unnamed: D193.2 (A), SW25.6
unnamed: D194.2 (A), SW26.6
unnamed: D195.2 (A), SW25.7
unnamed: D196.2 (A), SW26.7
unnamed: D197.2 (A), SW25.8
unnamed: D198.2 (A), SW26.8
unnamed: D199.2 (A), SW27.1
unnamed: D200.2 (A), SW28.1
unnamed: D201.2 (A), SW27.2
unnamed: D202.2 (A), SW28.2
unnamed: D203.2 (A), SW27.3
unnamed: D204.2 (A), SW28.3
unnamed: D205.2 (A), SW27.4
unnamed: D206.2 (A), SW28.4
unnamed: D207.2 (A), SW27.5
unnamed: D208.2 (A), SW28.5
unnamed: D209.2 (A), SW27.6
unnamed: D210.2 (A), SW28.6
unnamed: D211.2 (A), R15.2
unnamed: D211.1 (K), D213.1 (K), D215.1 (K), D217.1 (K), D219.1 (K), D221.1 (K), D223.1 (K), D225.1 (K), D227.1 (K), D229.1 (K), D231.1 (K), D233.1 (K), D235.1 (K), D237.1 (K), D239.1 (K), U4.7 (~Y7)
unnamed: D212.2 (A), R16.2
unnamed: D212.1 (K), D214.1 (K), D216.1 (K), D218.1 (K), D220.1 (K), D222.1 (K), D224.1 (K), D226.1 (K), D228.1 (K), D230.1 (K), D232.1 (K), D234.1 (K), D236.1 (K), D238.1 (K), D240.1 (K), U3.7 (~Y7)
unnamed: D213.2 (A), SW29.1
unnamed: D214.2 (A), SW30.1
unnamed: D215.2 (A), SW29.2
unnamed: D216.2 (A), SW30.2
unnamed: D217.2 (A), SW29.3
unnamed: D218.2 (A), SW30.3
unnamed: D219.2 (A), SW29.4
unnamed: D220.2 (A), SW30.4
unnamed: D221.2 (A), SW29.5
unnamed: D222.2 (A), SW30.5
unnamed: D223.2 (A), SW29.6
unnamed: D224.2 (A), SW30.6
unnamed: D225.2 (A), SW29.7
unnamed: D226.2 (A), SW30.7
unnamed: D227.2 (A), SW29.8
unnamed: D228.2 (A), SW30.8
unnamed: D229.2 (A), SW31.1
unnamed: D230.2 (A), SW32.1
unnamed: D231.2 (A), SW31.2
unnamed: D232.2 (A), SW32.2
unnamed: D233.2 (A), SW31.3
unnamed: D234.2 (A), SW32.3
unnamed: D235.2 (A), SW31.4
unnamed: D236.2 (A), SW32.4
unnamed: D237.2 (A), SW31.5
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

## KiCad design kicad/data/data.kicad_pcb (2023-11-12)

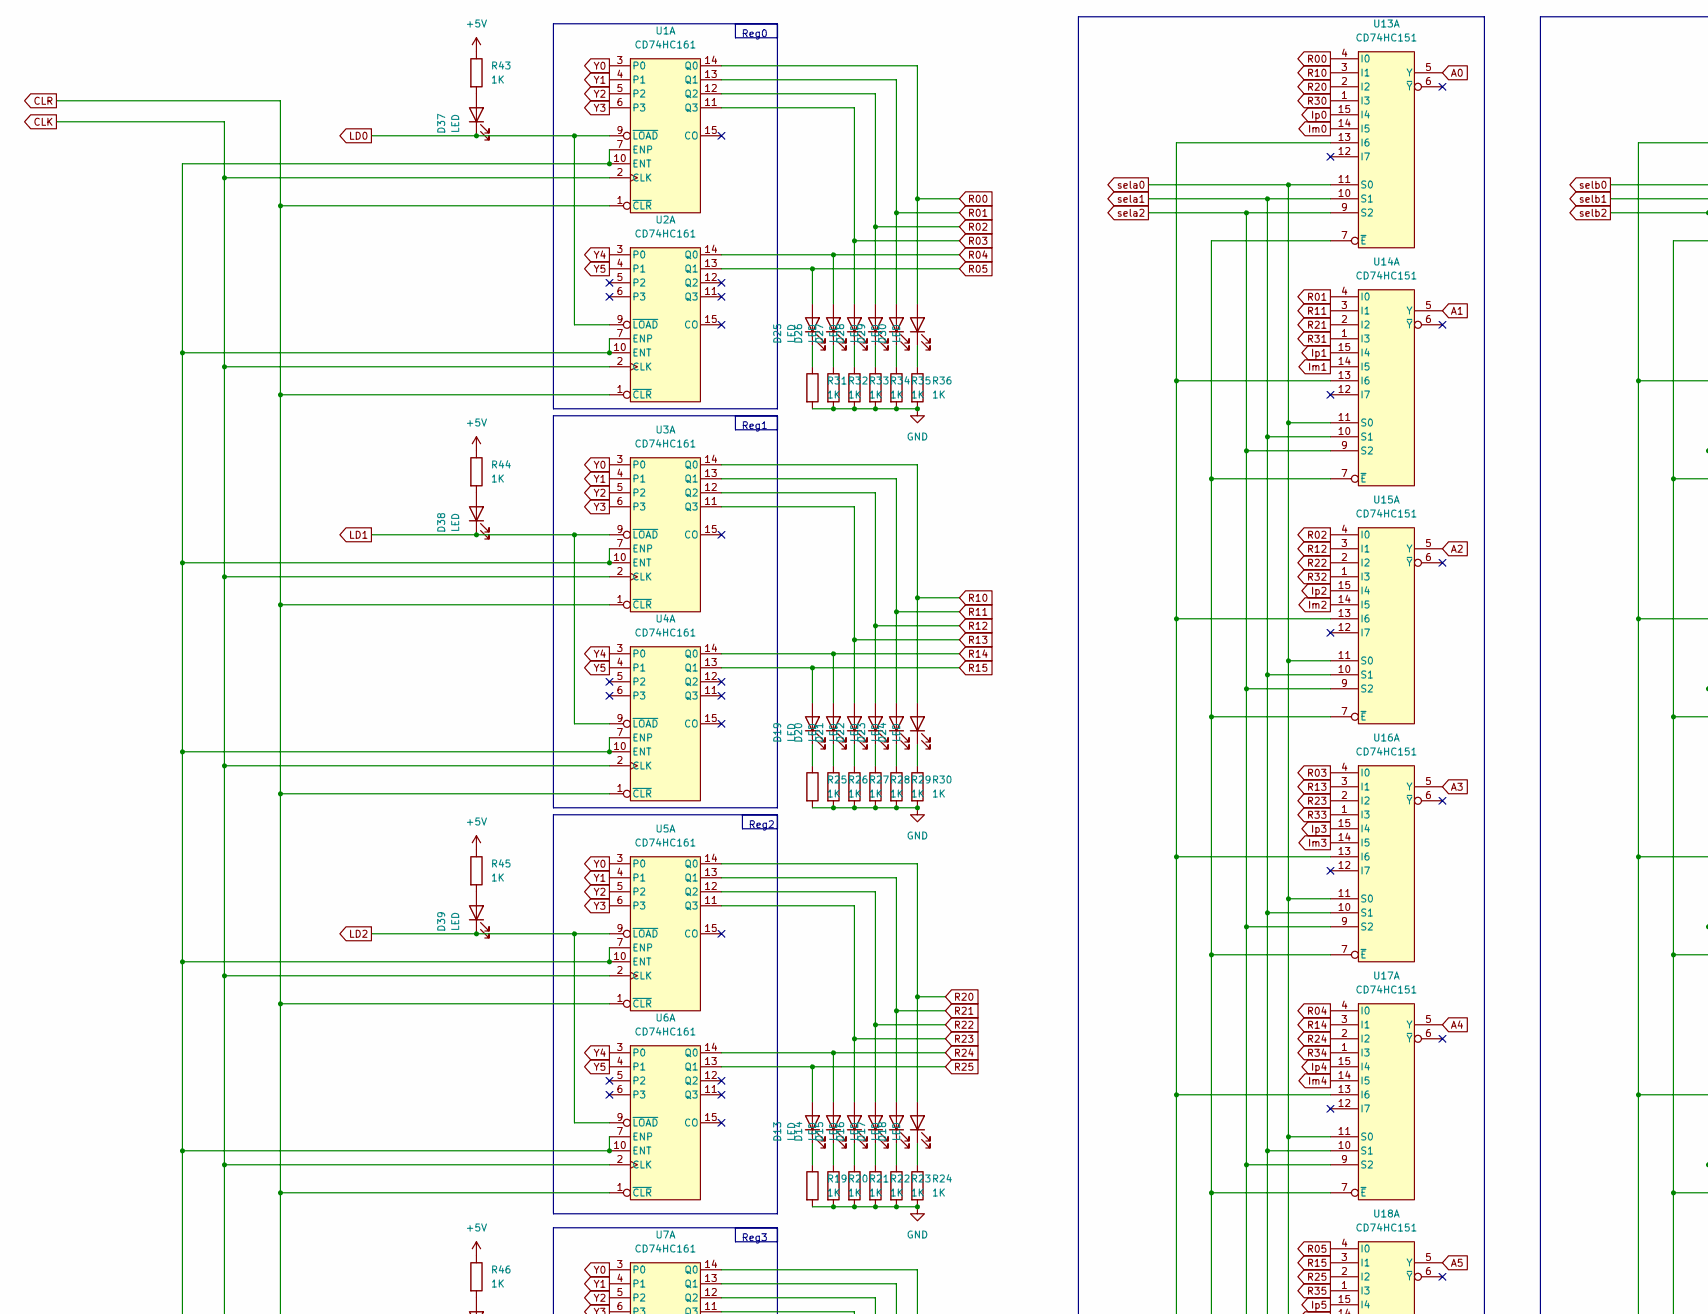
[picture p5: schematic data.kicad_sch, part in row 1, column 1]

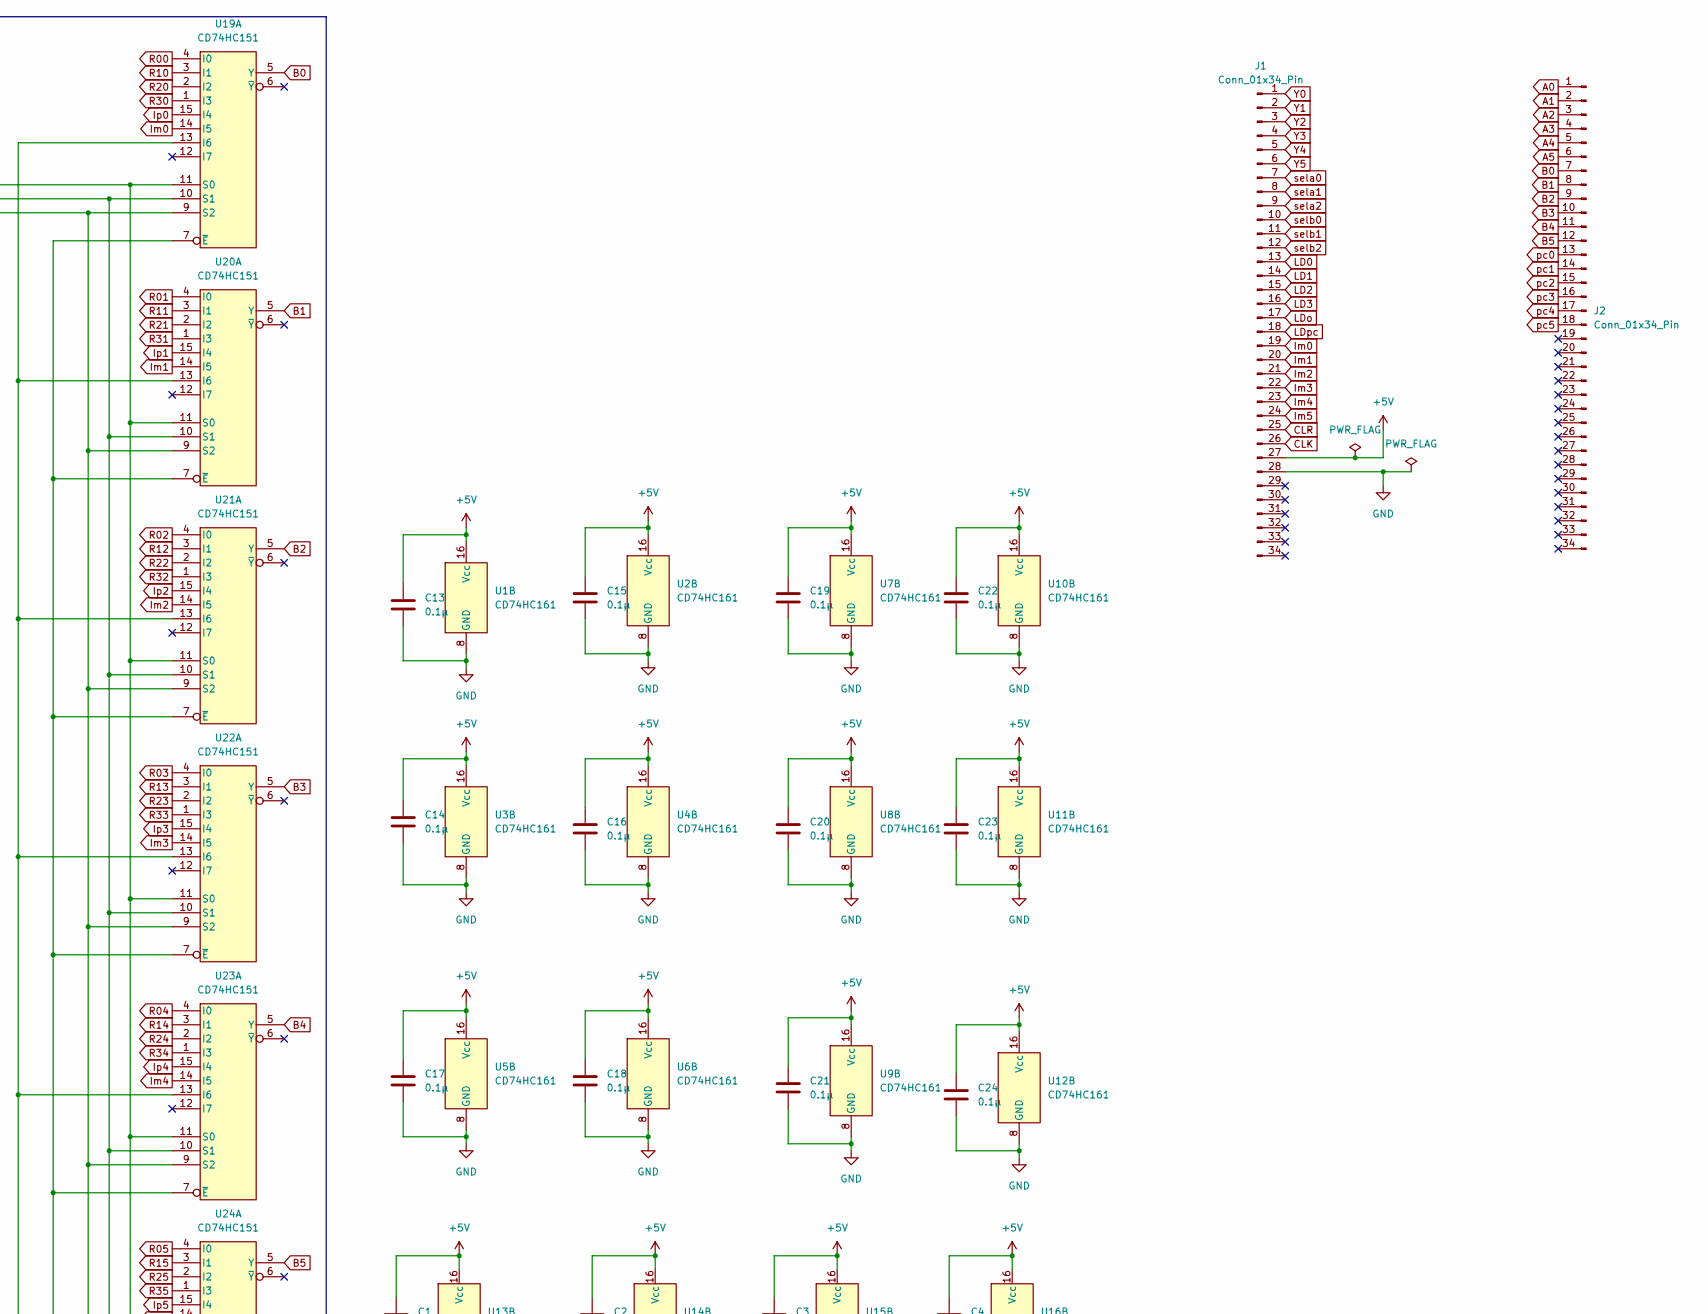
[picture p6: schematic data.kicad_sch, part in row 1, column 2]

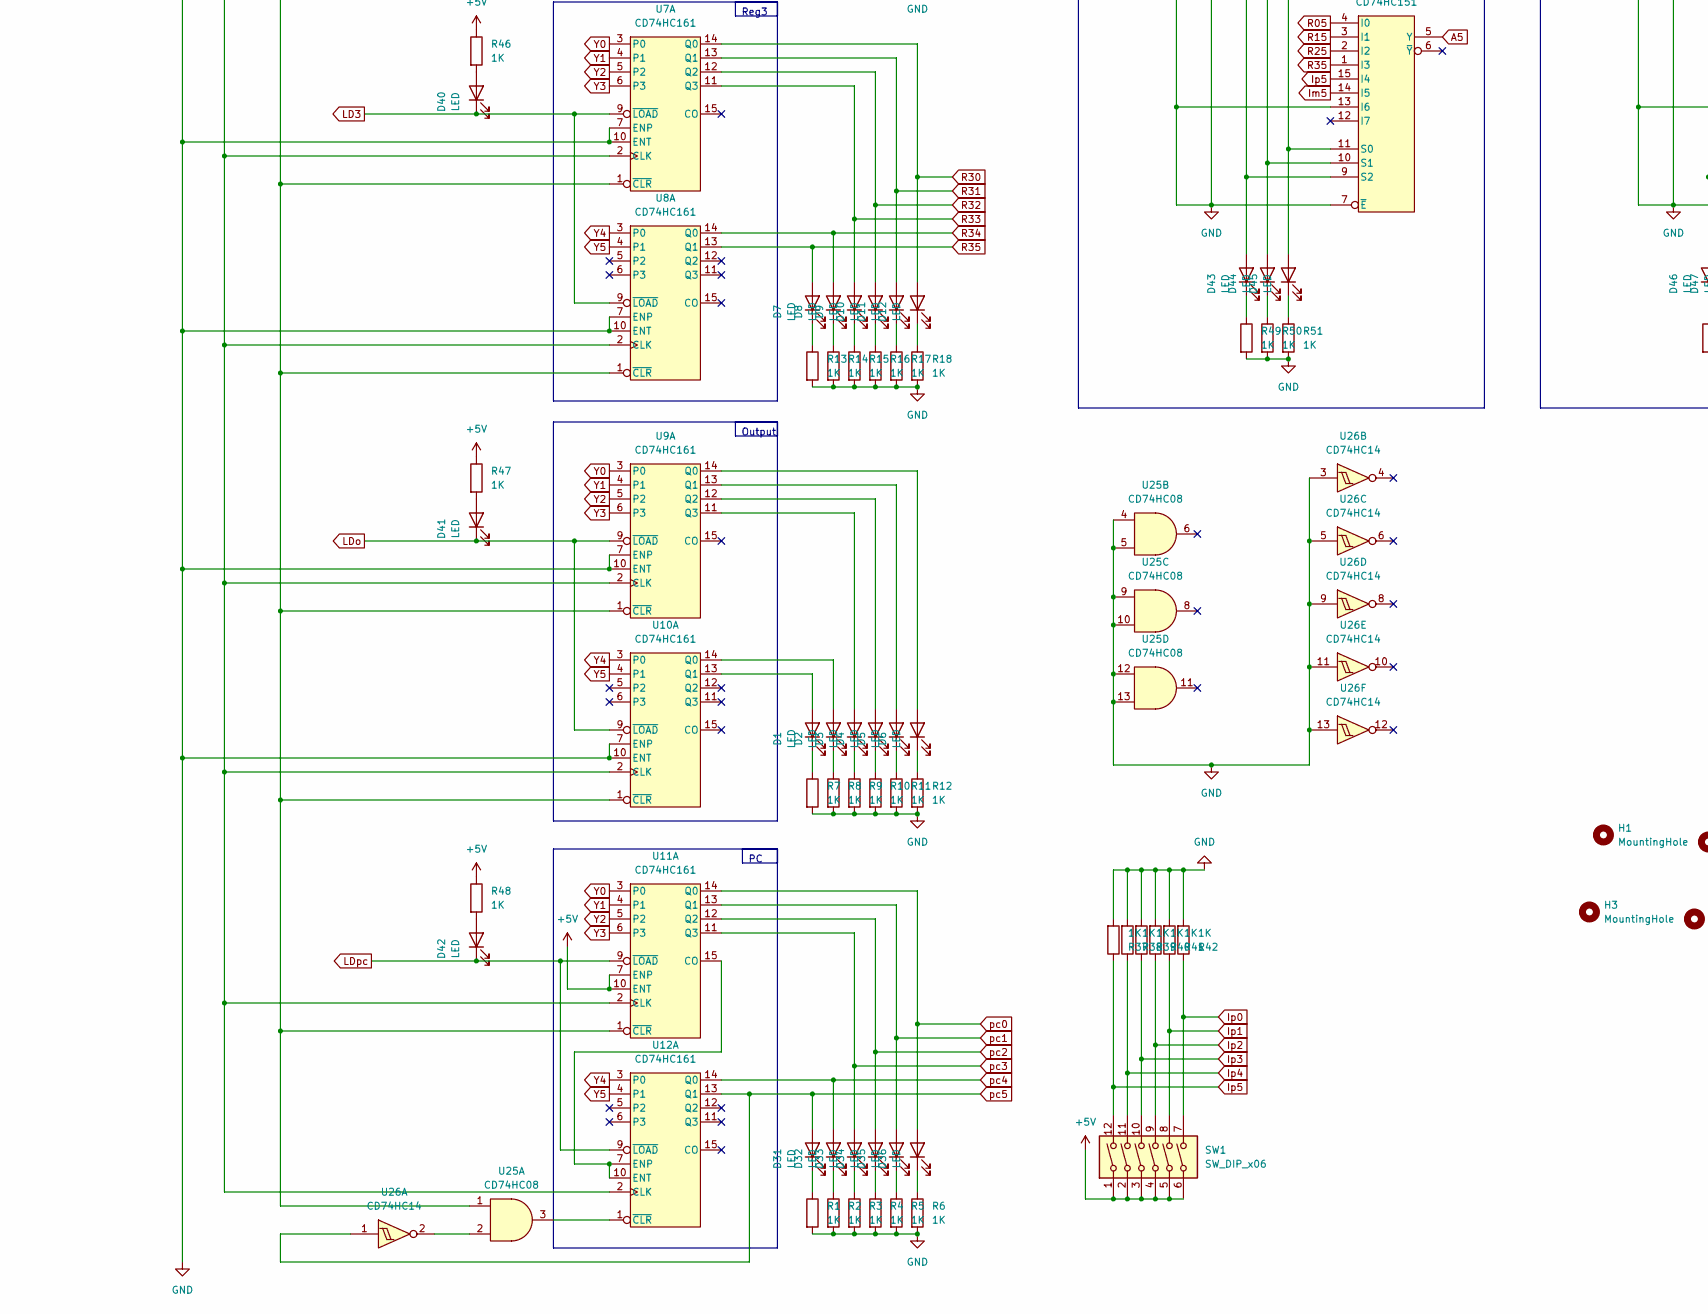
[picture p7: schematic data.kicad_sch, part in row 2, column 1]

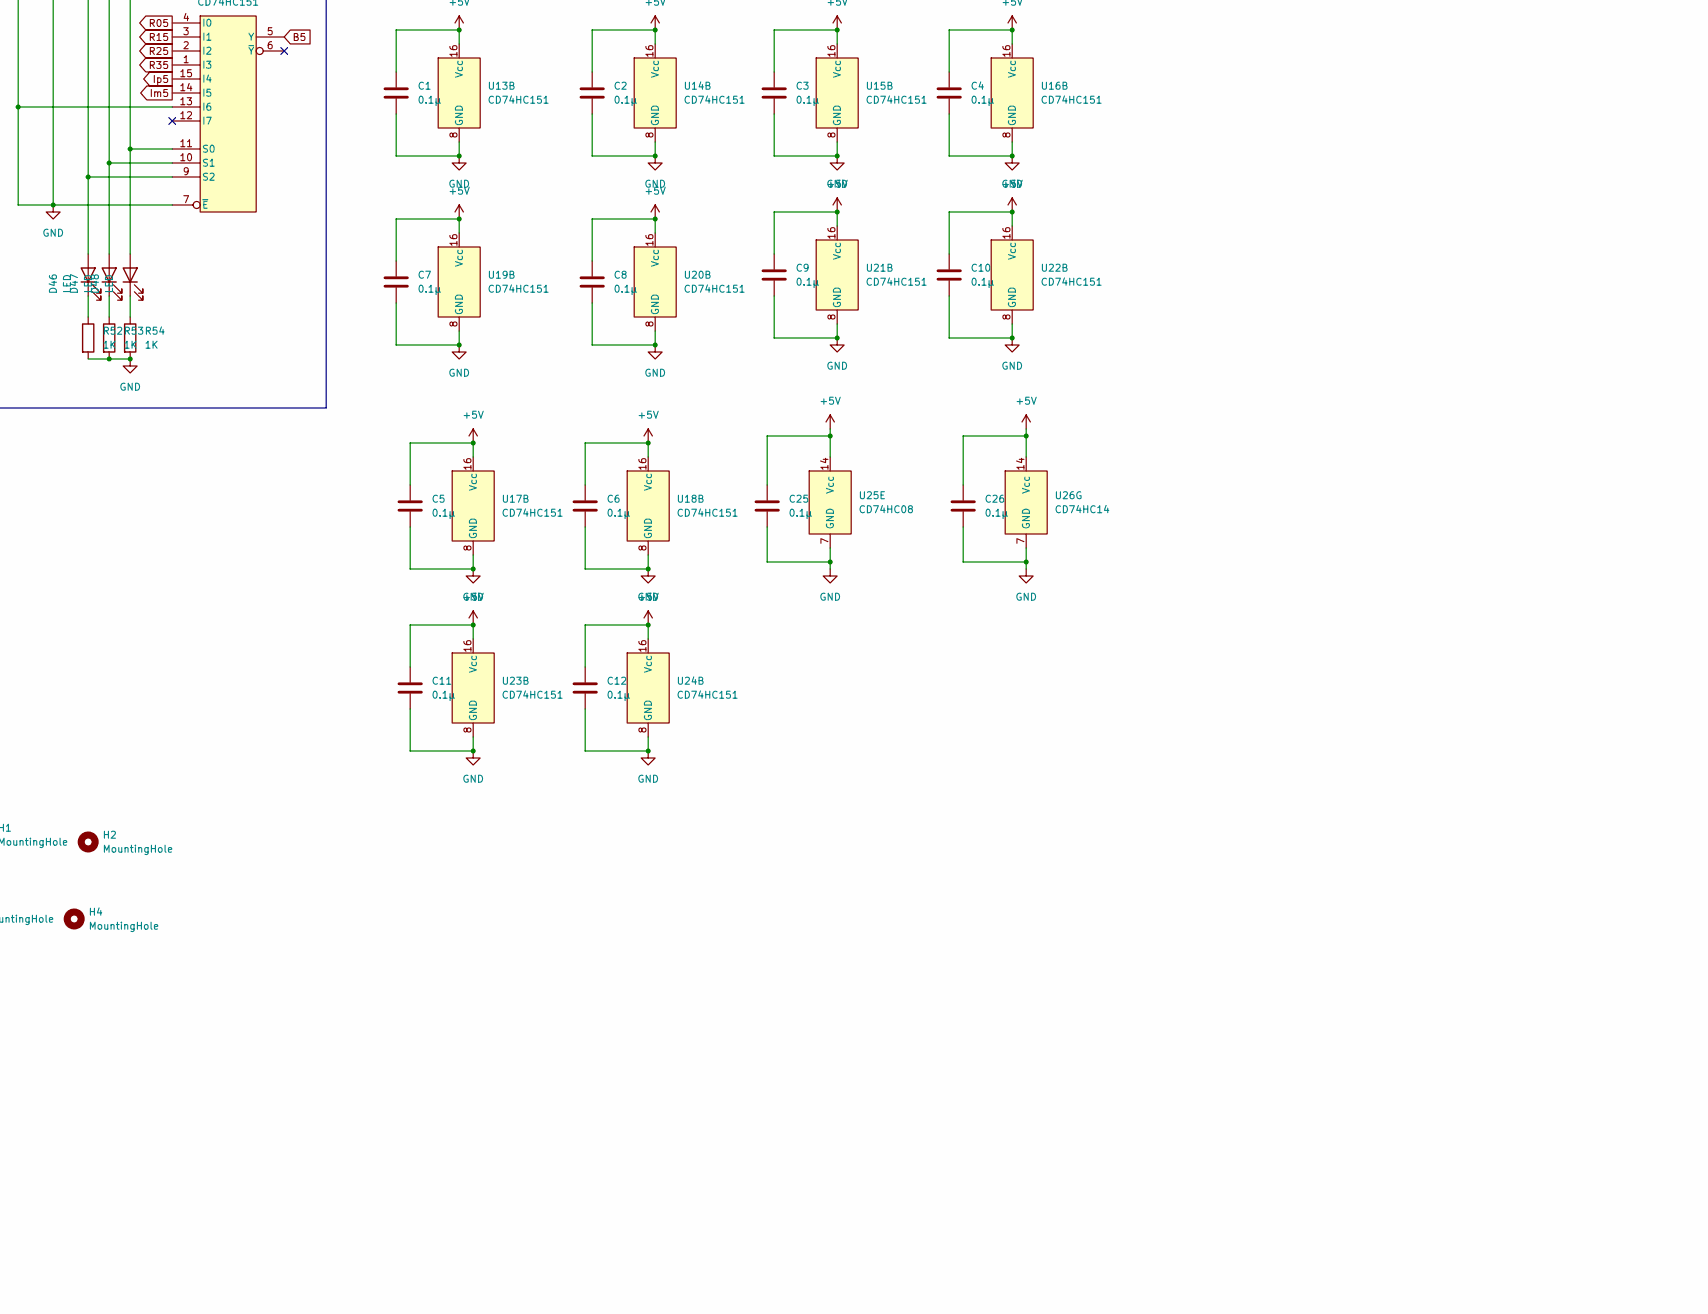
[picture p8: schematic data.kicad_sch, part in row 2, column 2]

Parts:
C1, C2, C3, C4, C5, C6, C7, C8, C9, C10, C11, C12, C13, C14, C15, C16, C17, C18, C19, C20, C21, C22, C23, C24, C25, C26: 0.1μ; C_Disc_D5.0mm_W2.5mm_P2.50mm
D1, D2, D3, D4, D5, D6, D7, D8, D9, D10, D11, D12, D13, D14, D15, D16, D17, D18, D19, D20, D21, D22, D23, D24, D25, D26, D27, D28, D29, D30, D31, D32, D33, D34, D35, D36, D37, D38, D39, D40, D41, D42, D43, D44, D45, D46, D47, D48: LED; LED_D3.0mm
H1, H2, H3, H4: MountingHole; MountingHole_3.2mm_M3
J1, J2: Conn_01x34_Pin; PinHeader_2x17_P2.54mm_Horizontal
R1, R2, R3, R4, R5, R6, R7, R8, R9, R10, R11, R12, R13, R14, R15, R16, R17, R18, R19, R20, R21, R22, R23, R24, R25, R26, R27, R28, R29, R30, R31, R32, R33, R34, R35, R36, R37, R38, R39, R40, R41, R42, R43, R44, R45, R46, R47, R48, R49, R50, R51, R52, R53, R54: 1K; R_Axial_DIN0207_L6.3mm_D2.5mm_P10.16mm_Horizontal
SW1: SW_DIP_x06; DIP-12_W7.62mm_Socket
U1, U2, U3, U4, U5, U6, U7, U8, U9, U10, U11, U12: CD74HC161; DIP-16_W7.62mm_Socket
U13, U14, U15, U16, U17, U18, U19, U20, U21, U22, U23, U24: CD74HC151; DIP-16_W7.62mm_Socket
U25: CD74HC08; DIP-14_W7.62mm_Socket
U26: CD74HC14; DIP-14_W7.62mm_Socket

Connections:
+5V: C1.1, C2.1, C3.1, C4.1, C5.1, C6.1, C7.1, C8.1, C9.1, C10.1, C11.1, C12.1, C13.1, C14.1, C15.1, C16.1, C17.1, C18.1, C19.1, C20.1, C21.1, C22.1, C23.1, C24.1, C25.1, C26.1, J1.27, R43.1, R44.1, R45.1, R46.1, R47.1, R48.1, SW1.1, SW1.2, SW1.3, SW1.4, SW1.5, SW1.6, U1.16 (Vcc), U2.16 (Vcc), U3.16 (Vcc), U4.16 (Vcc), U5.16 (Vcc), U6.16 (Vcc), U7.16 (Vcc), U8.16 (Vcc), U9.16 (Vcc), U10.16 (Vcc), U11.7 (ENP), U11.10 (ENT), U11.16 (Vcc), U12.16 (Vcc), U13.16 (Vcc), U14.16 (Vcc), U15.16 (Vcc), U16.16 (Vcc), U17.16 (Vcc), U18.16 (Vcc), U19.16 (Vcc), U20.16 (Vcc), U21.16 (Vcc), U22.16 (Vcc), U23.16 (Vcc), U24.16 (Vcc), U25.14 (Vcc), U26.14 (Vcc)
A0: J2.1, U13.5 (Y)
A1: J2.2, U14.5 (Y)
A2: J2.3, U15.5 (Y)
A3: J2.4, U16.5 (Y)
A4: J2.5, U17.5 (Y)
A5: J2.6, U18.5 (Y)
B0: J2.7, U19.5 (Y)
B1: J2.8, U20.5 (Y)
B2: J2.9, U21.5 (Y)
B3: J2.10, U22.5 (Y)
B4: J2.11, U23.5 (Y)
B5: J2.12, U24.5 (Y)
CLK: J1.26, U1.2 (CLK), U2.2 (CLK), U3.2 (CLK), U4.2 (CLK), U5.2 (CLK), U6.2 (CLK), U7.2 (CLK), U8.2 (CLK), U9.2 (CLK), U10.2 (CLK), U11.2 (CLK), U12.2 (CLK)
CLR: J1.25, U1.1 (~CLR), U2.1 (~CLR), U3.1 (~CLR), U4.1 (~CLR), U5.1 (~CLR), U6.1 (~CLR), U7.1 (~CLR), U8.1 (~CLR), U9.1 (~CLR), U10.1 (~CLR), U11.1 (~CLR), U25.1
GND: C1.2, C2.2, C3.2, C4.2, C5.2, C6.2, C7.2, C8.2, C9.2, C10.2, C11.2, C12.2, C13.2, C14.2, C15.2, C16.2, C17.2, C18.2, C19.2, C20.2, C21.2, C22.2, C23.2, C24.2, C25.2, C26.2, J1.28, R1.2, R2.2, R3.2, R4.2, R5.2, R6.2, R7.2, R8.2, R9.2, R10.2, R11.2, R12.2, R13.2, R14.2, R15.2, R16.2, R17.2, R18.2, R19.2, R20.2, R21.2, R22.2, R23.2, R24.2, R25.2, R26.2, R27.2, R28.2, R29.2, R30.2, R31.2, R32.2, R33.2, R34.2, R35.2, R36.2, R37.2, R38.2, R39.2, R40.2, R41.2, R42.2, R49.2, R50.2, R51.2, R52.2, R53.2, R54.2, U1.7 (ENP), U1.8 (GND), U1.10 (ENT), U2.7 (ENP), U2.8 (GND), U2.10 (ENT), U3.7 (ENP), U3.8 (GND), U3.10 (ENT), U4.7 (ENP), U4.8 (GND), U4.10 (ENT), U5.7 (ENP), U5.8 (GND), U5.10 (ENT), U6.7 (ENP), U6.8 (GND), U6.10 (ENT), U7.7 (ENP), U7.8 (GND), U7.10 (ENT), U8.7 (ENP), U8.8 (GND), U8.10 (ENT), U9.7 (ENP), U9.8 (GND), U9.10 (ENT), U10.7 (ENP), U10.8 (GND), U10.10 (ENT), U11.8 (GND), U12.8 (GND), U13.7 (~E), U13.8 (GND), U13.13 (I6), U14.7 (~E), U14.8 (GND), U14.13 (I6), U15.7 (~E), U15.8 (GND), U15.13 (I6), U16.7 (~E), U16.8 (GND), U16.13 (I6), U17.7 (~E), U17.8 (GND), U17.13 (I6), U18.7 (~E), U18.8 (GND), U18.13 (I6), U19.7 (~E), U19.8 (GND), U19.13 (I6), U20.7 (~E), U20.8 (GND), U20.13 (I6), U21.7 (~E), U21.8 (GND), U21.13 (I6), U22.7 (~E), U22.8 (GND), U22.13 (I6), U23.7 (~E), U23.8 (GND), U23.13 (I6), U24.7 (~E), U24.8 (GND), U24.13 (I6), U25.4, U25.5, U25.7 (GND), U25.9, U25.10, U25.12, U25.13, U26.3, U26.5, U26.7 (GND), U26.9, U26.11, U26.13
Im0: J1.19, U13.14 (I5), U19.14 (I5)
Im1: J1.20, U14.14 (I5), U20.14 (I5)
Im2: J1.21, U15.14 (I5), U21.14 (I5)
Im3: J1.22, U16.14 (I5), U22.14 (I5)
Im4: J1.23, U17.14 (I5), U23.14 (I5)
Im5: J1.24, U18.14 (I5), U24.14 (I5)
Ip0: R42.1, SW1.7, U13.15 (I4), U19.15 (I4)
Ip1: R41.1, SW1.8, U14.15 (I4), U20.15 (I4)
Ip2: R40.1, SW1.9, U15.15 (I4), U21.15 (I4)
Ip3: R39.1, SW1.10, U16.15 (I4), U22.15 (I4)
Ip4: R38.1, SW1.11, U17.15 (I4), U23.15 (I4)
Ip5: R37.1, SW1.12, U18.15 (I4), U24.15 (I4)
LD0: D37.1 (K), J1.13, U1.9 (~LOAD), U2.9 (~LOAD)
LD1: D38.1 (K), J1.14, U3.9 (~LOAD), U4.9 (~LOAD)
LD2: D39.1 (K), J1.15, U5.9 (~LOAD), U6.9 (~LOAD)
LD3: D40.1 (K), J1.16, U7.9 (~LOAD), U8.9 (~LOAD)
LDo: D41.1 (K), J1.17, U9.9 (~LOAD), U10.9 (~LOAD)
LDpc: D42.1 (K), J1.18, U11.9 (~LOAD), U12.9 (~LOAD)
unnamed: D1.2 (A), U10.13 (Q1)
unnamed: D1.1 (K), R7.1
unnamed: D2.2 (A), U10.14 (Q0)
unnamed: D2.1 (K), R8.1
unnamed: D3.2 (A), U9.11 (Q3)
unnamed: D3.1 (K), R9.1
unnamed: D4.2 (A), U9.12 (Q2)
unnamed: D4.1 (K), R10.1
unnamed: D5.2 (A), U9.13 (Q1)
unnamed: D5.1 (K), R11.1
unnamed: D6.2 (A), U9.14 (Q0)
unnamed: D6.1 (K), R12.1
unnamed: D7.1 (K), R13.1
unnamed: D8.1 (K), R14.1
unnamed: D9.1 (K), R15.1
unnamed: D10.1 (K), R16.1
unnamed: D11.1 (K), R17.1
unnamed: D12.1 (K), R18.1
unnamed: D13.1 (K), R19.1
unnamed: D14.1 (K), R20.1
unnamed: D15.1 (K), R21.1
unnamed: D16.1 (K), R22.1
unnamed: D17.1 (K), R23.1
unnamed: D18.1 (K), R24.1
unnamed: D19.1 (K), R25.1
unnamed: D20.1 (K), R26.1
unnamed: D21.1 (K), R27.1
unnamed: D22.1 (K), R28.1
unnamed: D23.1 (K), R29.1
unnamed: D24.1 (K), R30.1
unnamed: D25.1 (K), R31.1
unnamed: D26.1 (K), R32.1
unnamed: D27.1 (K), R33.1
unnamed: D28.1 (K), R34.1
unnamed: D29.1 (K), R35.1
unnamed: D30.1 (K), R36.1
unnamed: D31.1 (K), R1.1
unnamed: D32.1 (K), R2.1
unnamed: D33.1 (K), R3.1
unnamed: D34.1 (K), R4.1
unnamed: D35.1 (K), R5.1
unnamed: D36.1 (K), R6.1
unnamed: D37.2 (A), R43.2
unnamed: D38.2 (A), R44.2
unnamed: D39.2 (A), R45.2
unnamed: D40.2 (A), R46.2
unnamed: D41.2 (A), R47.2
unnamed: D42.2 (A), R48.2
unnamed: D43.1 (K), R49.1
unnamed: D44.1 (K), R50.1
unnamed: D45.1 (K), R51.1
unnamed: D46.1 (K), R52.1
unnamed: D47.1 (K), R53.1
unnamed: D48.1 (K), R54.1
unnamed: U11.15 (CO), U12.7 (ENP), U12.10 (ENT)
unnamed: U12.1 (~CLR), U25.3
unnamed: U25.2, U26.2
R00: D30.2 (A), U1.14 (Q0), U13.4 (I0), U19.4 (I0)
R01: D29.2 (A), U1.13 (Q1), U14.4 (I0), U20.4 (I0)
R02: D28.2 (A), U1.12 (Q2), U15.4 (I0), U21.4 (I0)
R03: D27.2 (A), U1.11 (Q3), U16.4 (I0), U22.4 (I0)
R04: D26.2 (A), U2.14 (Q0), U17.4 (I0), U23.4 (I0)
R05: D25.2 (A), U2.13 (Q1), U18.4 (I0), U24.4 (I0)
R10: D24.2 (A), U3.14 (Q0), U13.3 (I1), U19.3 (I1)
R11: D23.2 (A), U3.13 (Q1), U14.3 (I1), U20.3 (I1)
R12: D22.2 (A), U3.12 (Q2), U15.3 (I1), U21.3 (I1)
R13: D21.2 (A), U3.11 (Q3), U16.3 (I1), U22.3 (I1)
R14: D20.2 (A), U4.14 (Q0), U17.3 (I1), U23.3 (I1)
R15: D19.2 (A), U4.13 (Q1), U18.3 (I1), U24.3 (I1)
R20: D18.2 (A), U5.14 (Q0), U13.2 (I2), U19.2 (I2)
R21: D17.2 (A), U5.13 (Q1), U14.2 (I2), U20.2 (I2)
R22: D16.2 (A), U5.12 (Q2), U15.2 (I2), U21.2 (I2)
R23: D15.2 (A), U5.11 (Q3), U16.2 (I2), U22.2 (I2)
R24: D14.2 (A), U6.14 (Q0), U17.2 (I2), U23.2 (I2)
R25: D13.2 (A), U6.13 (Q1), U18.2 (I2), U24.2 (I2)
R30: D12.2 (A), U7.14 (Q0), U13.1 (I3), U19.1 (I3)
R31: D11.2 (A), U7.13 (Q1), U14.1 (I3), U20.1 (I3)
R32: D10.2 (A), U7.12 (Q2), U15.1 (I3), U21.1 (I3)
R33: D9.2 (A), U7.11 (Q3), U16.1 (I3), U22.1 (I3)
R34: D8.2 (A), U8.14 (Q0), U17.1 (I3), U23.1 (I3)
R35: D7.2 (A), U8.13 (Q1), U18.1 (I3), U24.1 (I3)
Y0: J1.1, U1.3 (P0), U3.3 (P0), U5.3 (P0), U7.3 (P0), U9.3 (P0), U11.3 (P0)
Y1: J1.2, U1.4 (P1), U3.4 (P1), U5.4 (P1), U7.4 (P1), U9.4 (P1), U11.4 (P1)
Y2: J1.3, U1.5 (P2), U3.5 (P2), U5.5 (P2), U7.5 (P2), U9.5 (P2), U11.5 (P2)
Y3: J1.4, U1.6 (P3), U3.6 (P3), U5.6 (P3), U7.6 (P3), U9.6 (P3), U11.6 (P3)
Y4: J1.5, U2.3 (P0), U4.3 (P0), U6.3 (P0), U8.3 (P0), U10.3 (P0), U12.3 (P0)
Y5: J1.6, U2.4 (P1), U4.4 (P1), U6.4 (P1), U8.4 (P1), U10.4 (P1), U12.4 (P1)
pc0: D36.2 (A), J2.13, U11.14 (Q0)
pc1: D35.2 (A), J2.14, U11.13 (Q1)
pc2: D34.2 (A), J2.15, U11.12 (Q2)
pc3: D33.2 (A), J2.16, U11.11 (Q3)
pc4: D32.2 (A), J2.17, U12.14 (Q0)
pc5: D31.2 (A), J2.18, U12.13 (Q1), U26.1
sela0: D45.2 (A), J1.7, U13.11 (S0), U14.11 (S0), U15.11 (S0), U16.11 (S0), U17.11 (S0), U18.11 (S0)
sela1: D44.2 (A), J1.8, U13.10 (S1), U14.10 (S1), U15.10 (S1), U16.10 (S1), U17.10 (S1), U18.10 (S1)
sela2: D43.2 (A), J1.9, U13.9 (S2), U14.9 (S2), U15.9 (S2), U16.9 (S2), U17.9 (S2), U18.9 (S2)
selb0: D48.2 (A), J1.10, U19.11 (S0), U20.11 (S0), U21.11 (S0), U22.11 (S0), U23.11 (S0), U24.11 (S0)
selb1: D47.2 (A), J1.11, U19.10 (S1), U20.10 (S1), U21.10 (S1), U22.10 (S1), U23.10 (S1), U24.10 (S1)
selb2: D46.2 (A), J1.12, U19.9 (S2), U20.9 (S2), U21.9 (S2), U22.9 (S2), U23.9 (S2), U24.9 (S2)

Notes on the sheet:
Reg3
Reg0
Reg1
Output
Reg2

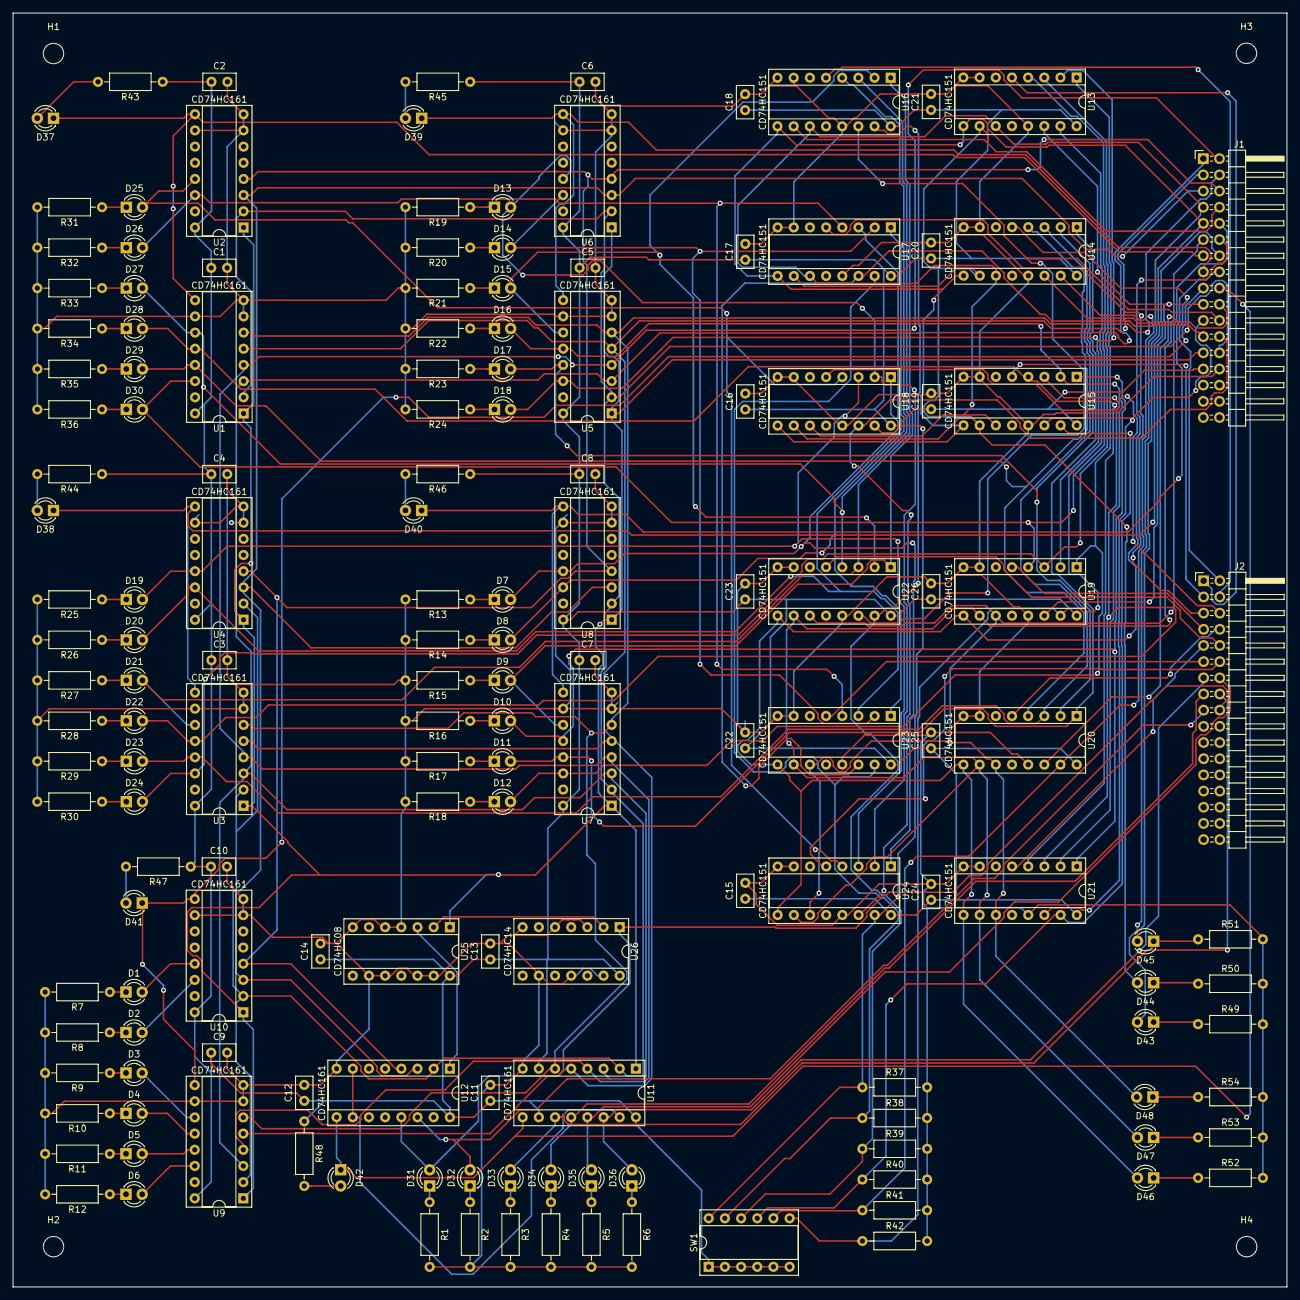
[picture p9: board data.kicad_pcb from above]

Board: 2 copper layers, 200.0 x 200.0 mm, 161 parts (0 on the bottom side), 133 nets.

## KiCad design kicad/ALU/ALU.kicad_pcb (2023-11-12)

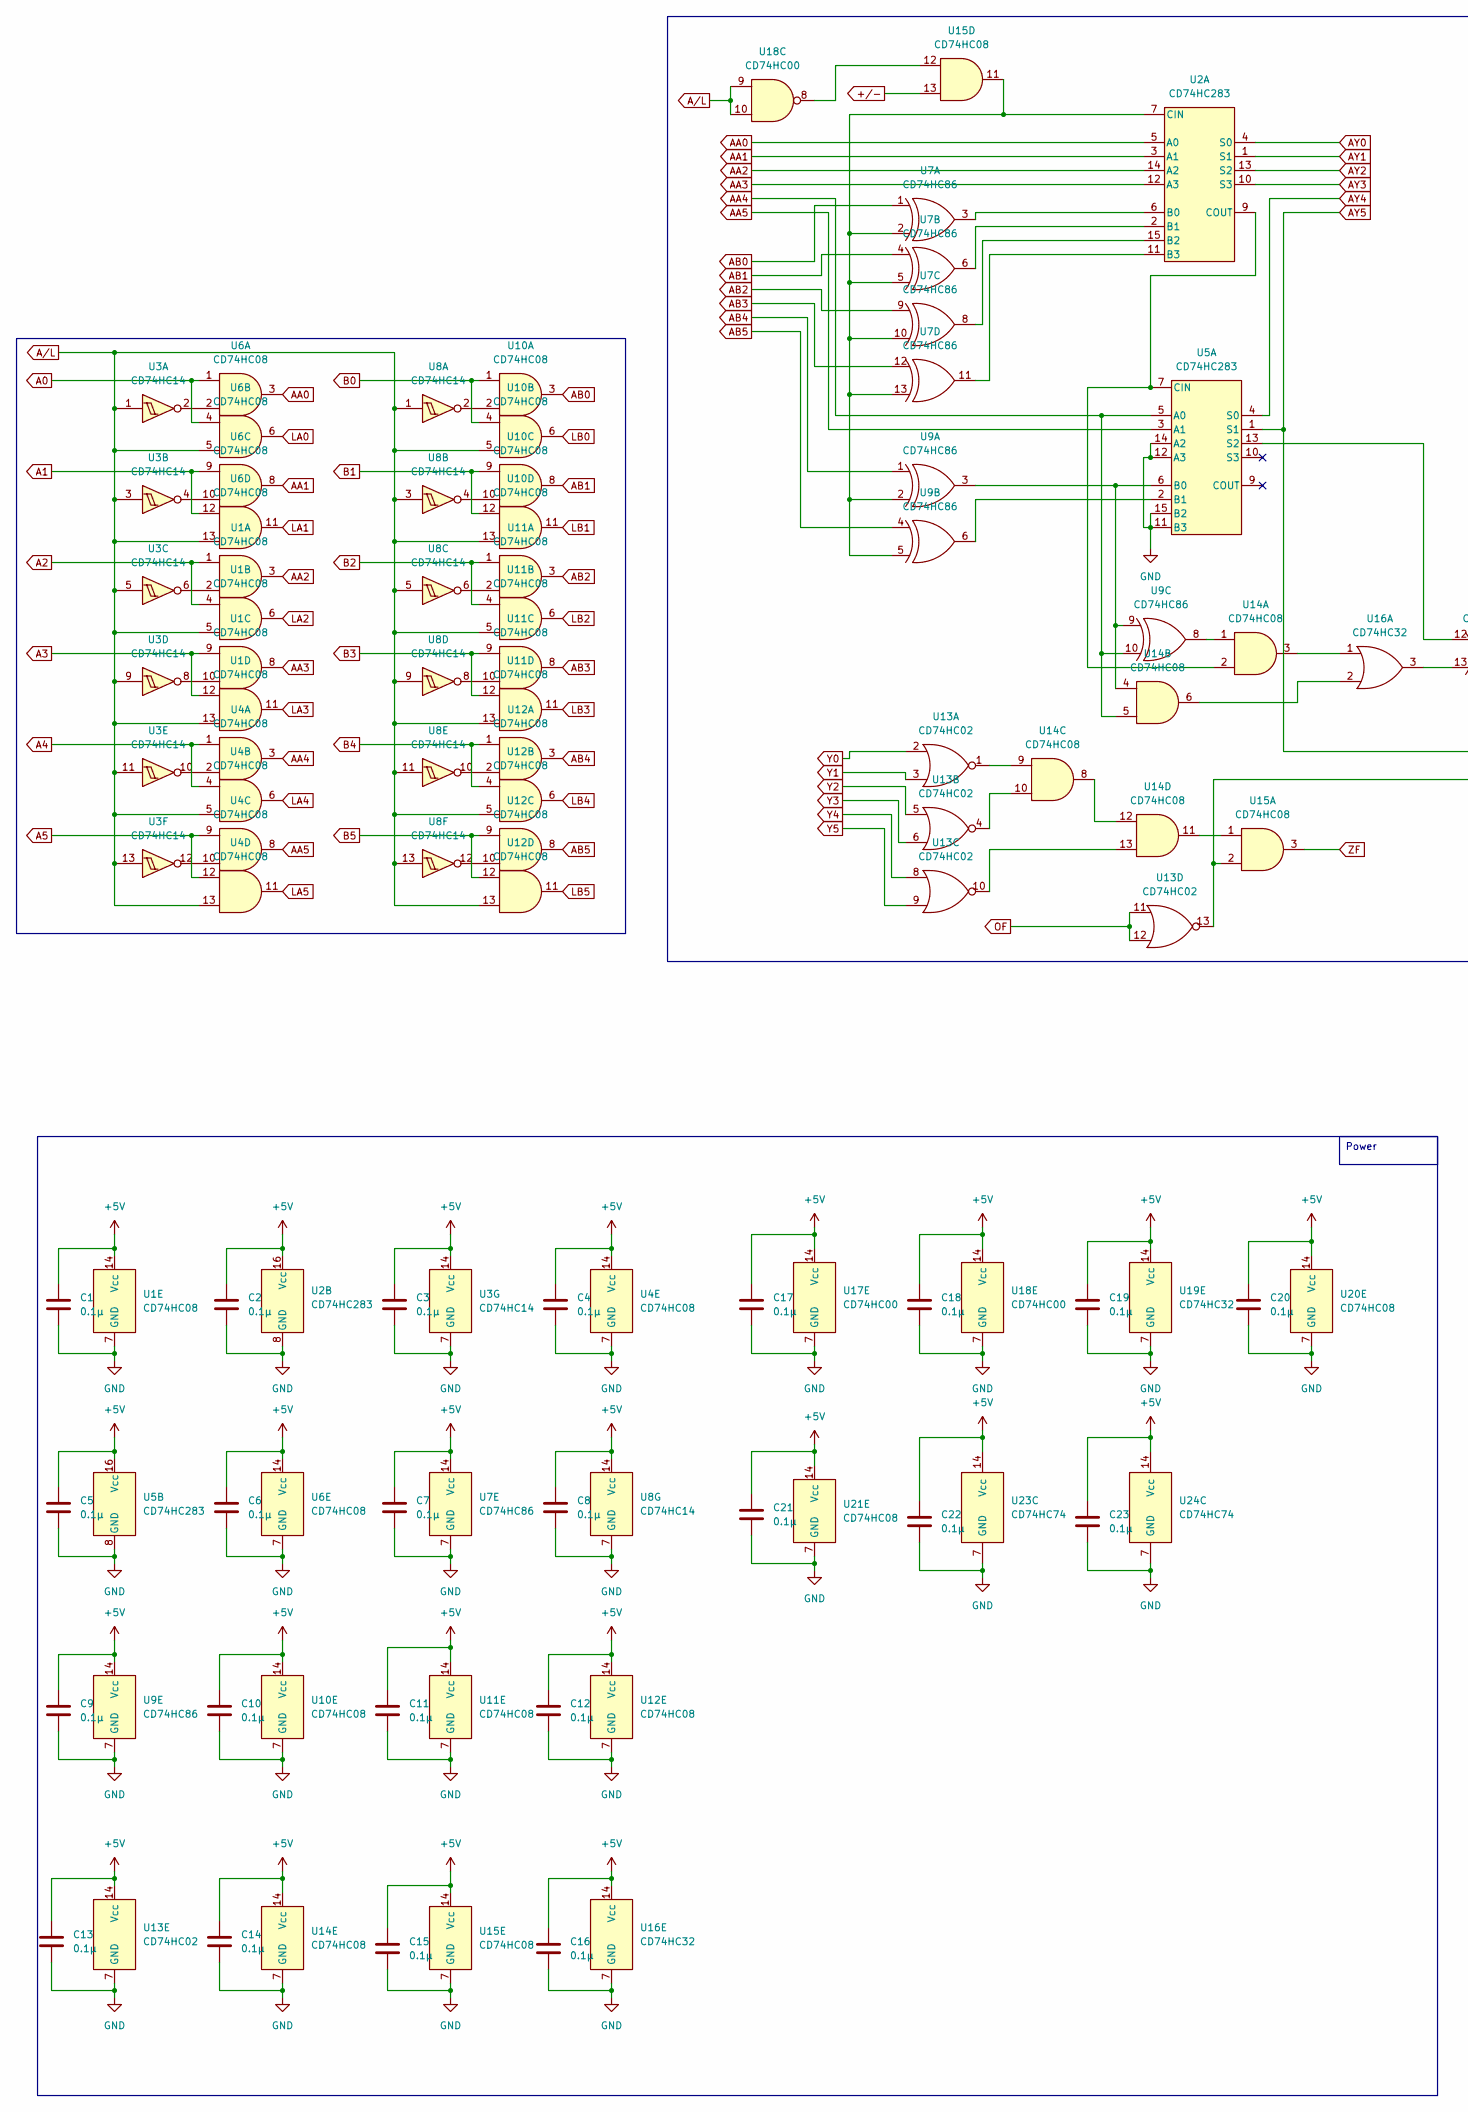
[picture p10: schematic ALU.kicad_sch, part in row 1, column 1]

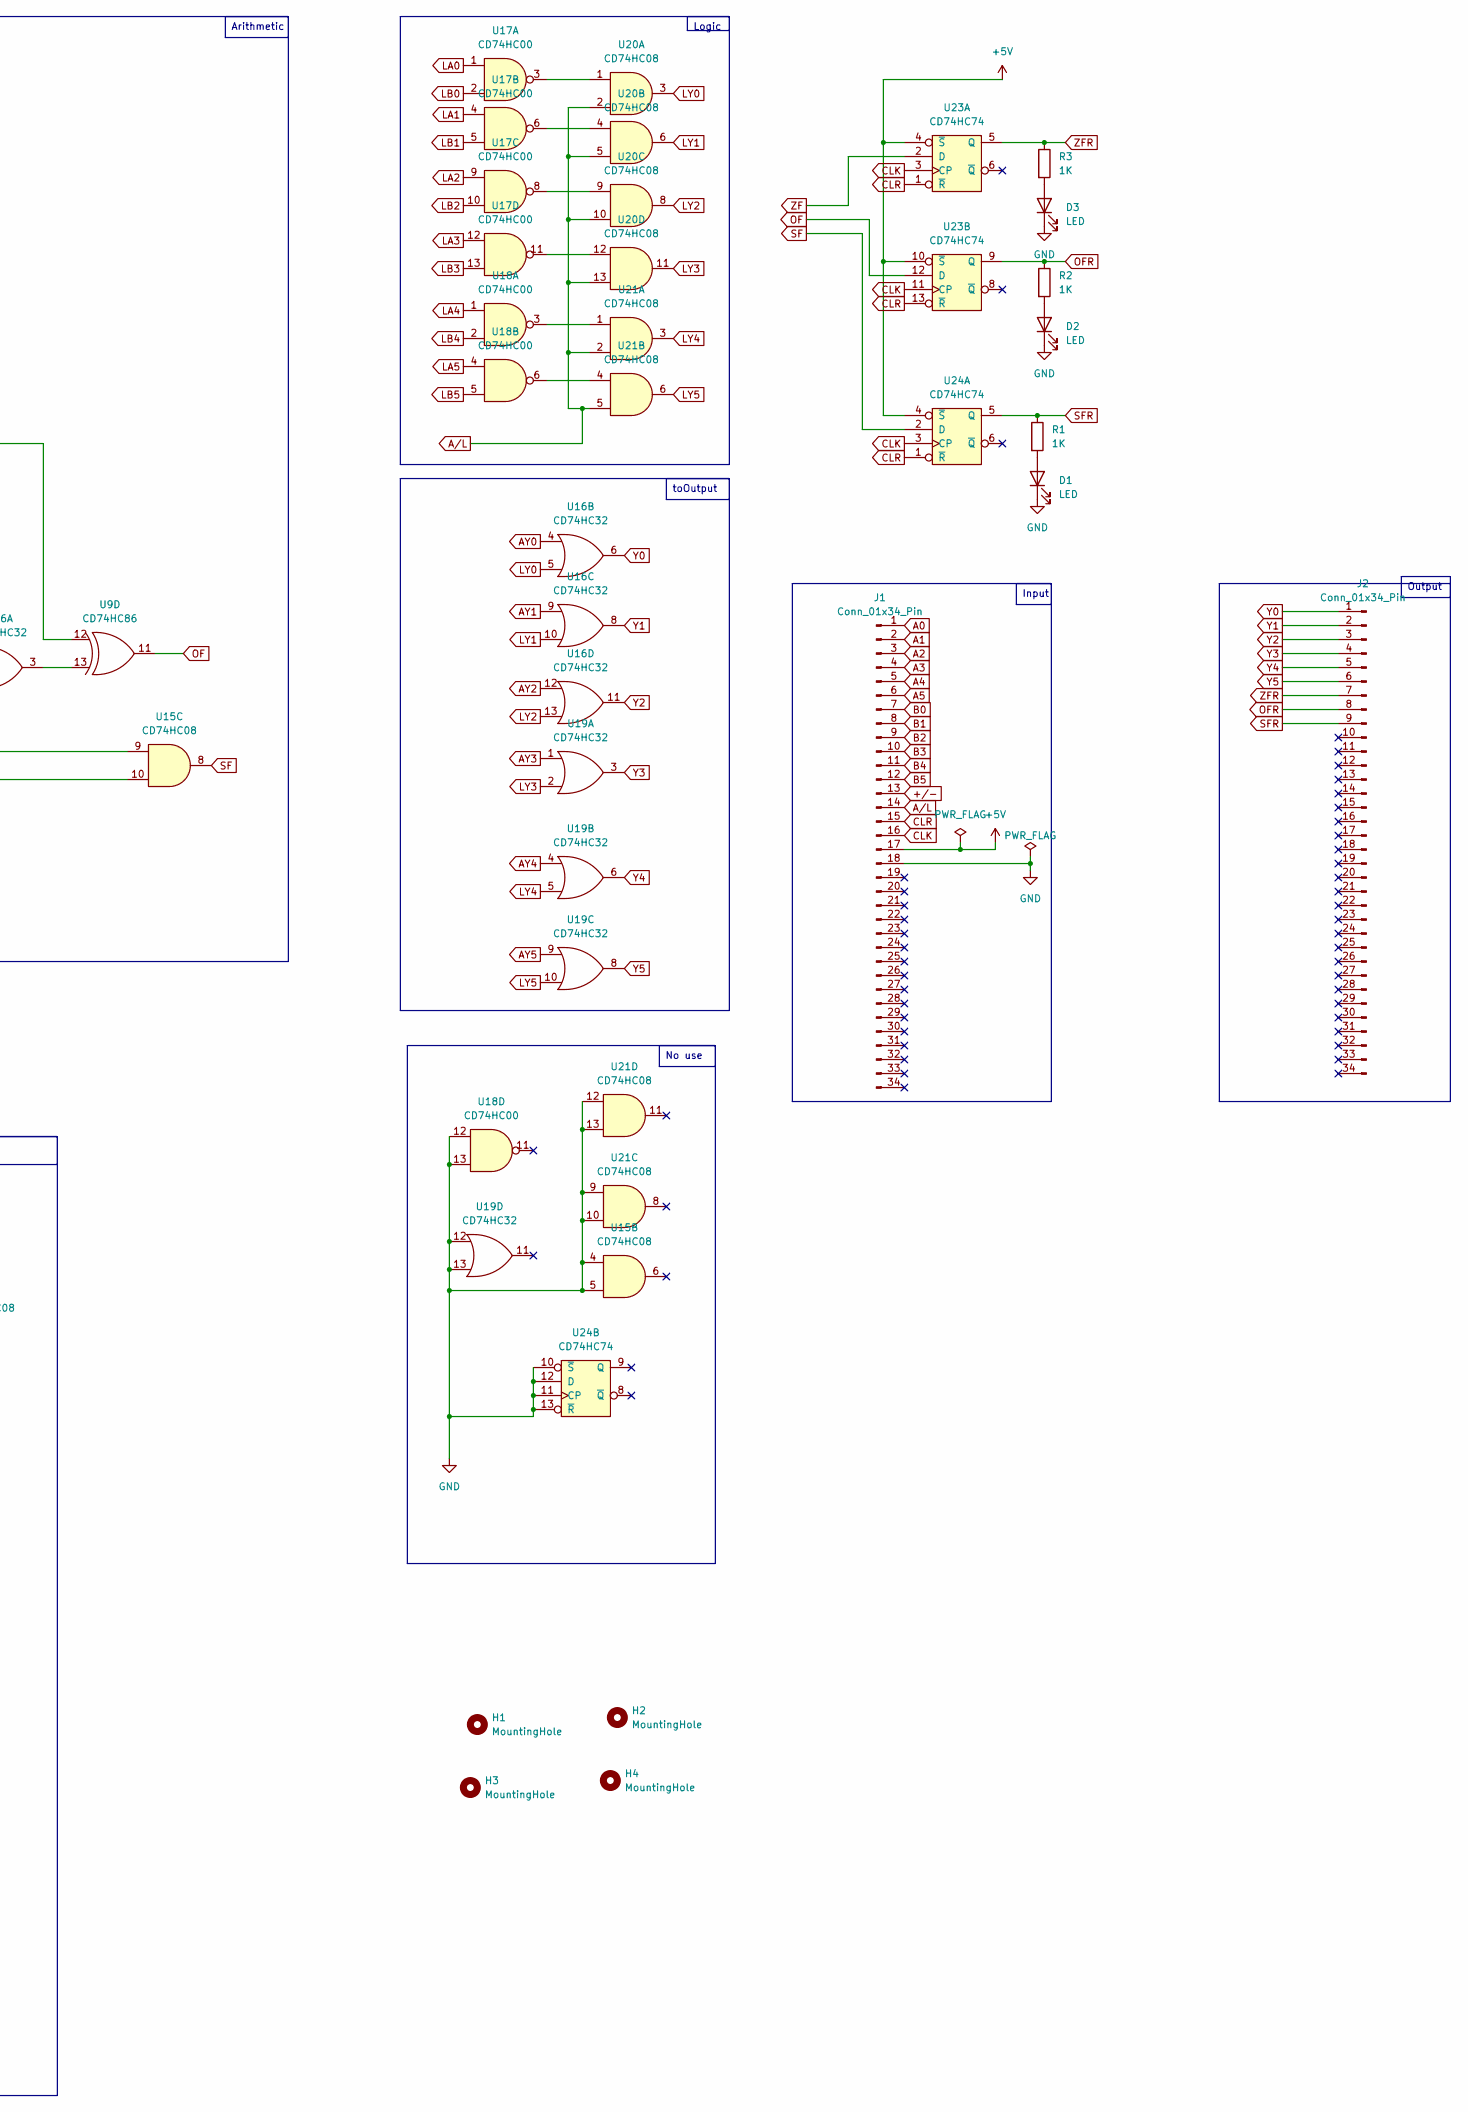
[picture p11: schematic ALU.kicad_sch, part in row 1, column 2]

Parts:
C1, C2, C3, C4, C5, C6, C7, C8, C9, C10, C11, C12, C13, C14, C15, C16, C17, C18, C19, C20, C21, C22, C23: 0.1μ; C_Disc_D5.0mm_W2.5mm_P2.50mm
D1, D2, D3: LED; LED_D3.0mm
H1, H2, H3, H4: MountingHole; MountingHole_3.2mm_M3
J1, J2: Conn_01x34_Pin; PinHeader_2x17_P2.54mm_Horizontal
R1, R2, R3: 1K; R_Axial_DIN0207_L6.3mm_D2.5mm_P10.16mm_Horizontal
U1, U4, U6, U10, U11, U12, U14, U15, U20, U21: CD74HC08; DIP-14_W7.62mm_Socket
U2, U5: CD74HC283; DIP-16_W7.62mm_Socket
U3, U8: CD74HC14; DIP-14_W7.62mm_Socket
U7, U9: CD74HC86; DIP-14_W7.62mm_Socket
U13: CD74HC02; DIP-14_W7.62mm_Socket
U16, U19: CD74HC32; DIP-14_W7.62mm_Socket
U17, U18: CD74HC00; DIP-14_W7.62mm_Socket
U23, U24: CD74HC74; DIP-14_W7.62mm_Socket

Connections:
+5V: C1.1, C2.1, C3.1, C4.1, C5.1, C6.1, C7.1, C8.1, C9.1, C10.1, C11.1, C12.1, C13.1, C14.1, C15.1, C16.1, C17.1, C18.1, C19.1, C20.1, C21.1, C22.1, C23.1, J1.17, U1.14 (Vcc), U2.16 (Vcc), U3.14 (Vcc), U4.14 (Vcc), U5.16 (Vcc), U6.14 (Vcc), U7.14 (Vcc), U8.14 (Vcc), U9.14 (Vcc), U10.14 (Vcc), U11.14 (Vcc), U12.14 (Vcc), U13.14 (Vcc), U14.14 (Vcc), U15.14 (Vcc), U16.14 (Vcc), U17.14 (Vcc), U18.14 (Vcc), U19.14 (Vcc), U20.14 (Vcc), U21.14 (Vcc), U23.4 (~S), U23.10 (~S), U23.14 (Vcc), U24.4 (~S), U24.14 (Vcc)
+/-: J1.13, U15.13
A0: J1.1, U6.1, U6.4
A1: J1.2, U6.9, U6.12
A2: J1.3, U1.1, U1.4
A3: J1.4, U1.9, U1.12
A4: J1.5, U4.1, U4.4
A5: J1.6, U4.9, U4.12
AA0: U2.5 (A0), U6.3
AA1: U2.3 (A1), U6.8
AA2: U1.3, U2.14 (A2)
AA3: U1.8, U2.12 (A3)
AA4: U4.3, U5.5 (A0), U9.10, U14.5
AA5: U4.8, U5.3 (A1)
AB0: U7.1, U10.3
AB1: U7.4, U10.8
AB2: U7.9, U11.3
AB3: U7.12, U11.8
AB4: U9.1, U12.3
AB5: U9.4, U12.8
AY0: U2.4 (S0), U16.4
AY1: U2.1 (S1), U16.9
AY2: U2.13 (S2), U16.12
AY3: U2.10 (S3), U19.1
AY4: U5.4 (S0), U19.4
AY5: U5.1 (S1), U15.9, U19.9
A/L: J1.14, U1.5, U1.13, U3.1, U3.3, U3.5, U3.9, U3.11, U3.13, U4.5, U4.13, U6.5, U6.13, U8.1, U8.3, U8.5, U8.9, U8.11, U8.13, U10.5, U10.13, U11.5, U11.13, U12.5, U12.13, U18.9, U18.10, U20.2, U20.5, U20.10, U20.13, U21.2, U21.5
B0: J1.7, U10.1, U10.4
B1: J1.8, U10.9, U10.12
B2: J1.9, U11.1, U11.4
B3: J1.10, U11.9, U11.12
B4: J1.11, U12.1, U12.4
B5: J1.12, U12.9, U12.12
CLK: J1.16, U23.3 (CP), U23.11 (CP), U24.3 (CP)
CLR: J1.15, U23.1 (~R), U23.13 (~R), U24.1 (~R)
GND: C1.2, C2.2, C3.2, C4.2, C5.2, C6.2, C7.2, C8.2, C9.2, C10.2, C11.2, C12.2, C13.2, C14.2, C15.2, C16.2, C17.2, C18.2, C19.2, C20.2, C21.2, C22.2, C23.2, D1.1 (K), D2.1 (K), D3.1 (K), J1.18, U1.7 (GND), U2.8 (GND), U3.7 (GND), U4.7 (GND), U5.8 (GND), U5.11 (B3), U5.12 (A3), U5.14 (A2), U5.15 (B2), U6.7 (GND), U7.7 (GND), U8.7 (GND), U9.7 (GND), U10.7 (GND), U11.7 (GND), U12.7 (GND), U13.7 (GND), U14.7 (GND), U15.4, U15.5, U15.7 (GND), U16.7 (GND), U17.7 (GND), U18.7 (GND), U18.12, U18.13, U19.7 (GND), U19.12, U19.13, U20.7 (GND), U21.7 (GND), U21.9, U21.10, U21.12, U21.13, U23.7 (GND), U24.7 (GND), U24.10 (~S), U24.11 (CP), U24.12 (D), U24.13 (~R)
LA0: U6.6, U17.1
LA1: U6.11, U17.4
LA2: U1.6, U17.9
LA3: U1.11, U17.12
LA4: U4.6, U18.1
LA5: U4.11, U18.4
LB0: U10.6, U17.2
LB1: U10.11, U17.5
LB2: U11.6, U17.10
LB3: U11.11, U17.13
LB4: U12.6, U18.2
LB5: U12.11, U18.5
LY0: U16.5, U20.3
LY1: U16.10, U20.6
LY2: U16.13, U20.8
LY3: U19.2, U20.11
LY4: U19.5, U21.3
LY5: U19.10, U21.6
unnamed: D1.2 (A), R1.2
unnamed: D2.2 (A), R2.2
unnamed: D3.2 (A), R3.2
unnamed: U1.2, U3.6
unnamed: U1.10, U3.8
unnamed: U2.6 (B0), U7.3
unnamed: U2.2 (B1), U7.6
unnamed: U2.15 (B2), U7.8
unnamed: U2.11 (B3), U7.11
unnamed: U2.7 (CIN), U7.2, U7.5, U7.10, U7.13, U9.2, U9.5, U15.11
unnamed: U2.9 (COUT), U5.7 (CIN), U14.2
unnamed: U3.2, U6.2
unnamed: U3.4, U6.10
unnamed: U3.10, U4.2
unnamed: U3.12, U4.10
unnamed: U5.6 (B0), U9.3, U9.9, U14.4
unnamed: U5.2 (B1), U9.6
unnamed: U5.13 (S2), U9.12
unnamed: U8.2, U10.2
unnamed: U8.4, U10.10
unnamed: U8.6, U11.2
unnamed: U8.8, U11.10
unnamed: U8.10, U12.2
unnamed: U8.12, U12.10
unnamed: U13.1, U14.9
unnamed: U13.4, U14.10
unnamed: U13.10, U14.13
unnamed: U13.13, U15.2, U15.10
unnamed: U9.8, U14.1
unnamed: U14.3, U16.1
unnamed: U14.6, U16.2
unnamed: U14.11, U15.1
unnamed: U14.8, U14.12
unnamed: U15.12, U18.8
unnamed: U9.13, U16.3
unnamed: U17.3, U20.1
unnamed: U17.6, U20.4
unnamed: U17.8, U20.9
unnamed: U17.11, U20.12
unnamed: U18.3, U21.1
unnamed: U18.6, U21.4
OF: U9.11, U13.11, U13.12, U23.12 (D)
OFR: J2.8, R2.1, U23.9 (Q)
SF: U15.8, U24.2 (D)
SFR: J2.9, R1.1, U24.5 (Q)
Y0: J2.1, U13.2, U16.6
Y1: J2.2, U13.3, U16.8
Y2: J2.3, U13.5, U16.11
Y3: J2.4, U13.6, U19.3
Y4: J2.5, U13.8, U19.6
Y5: J2.6, U13.9, U19.8
ZF: U15.3, U23.2 (D)
ZFR: J2.7, R3.1, U23.5 (Q)

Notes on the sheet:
Output
Arithmetic
Input
toOutput
No use
Logic
Power

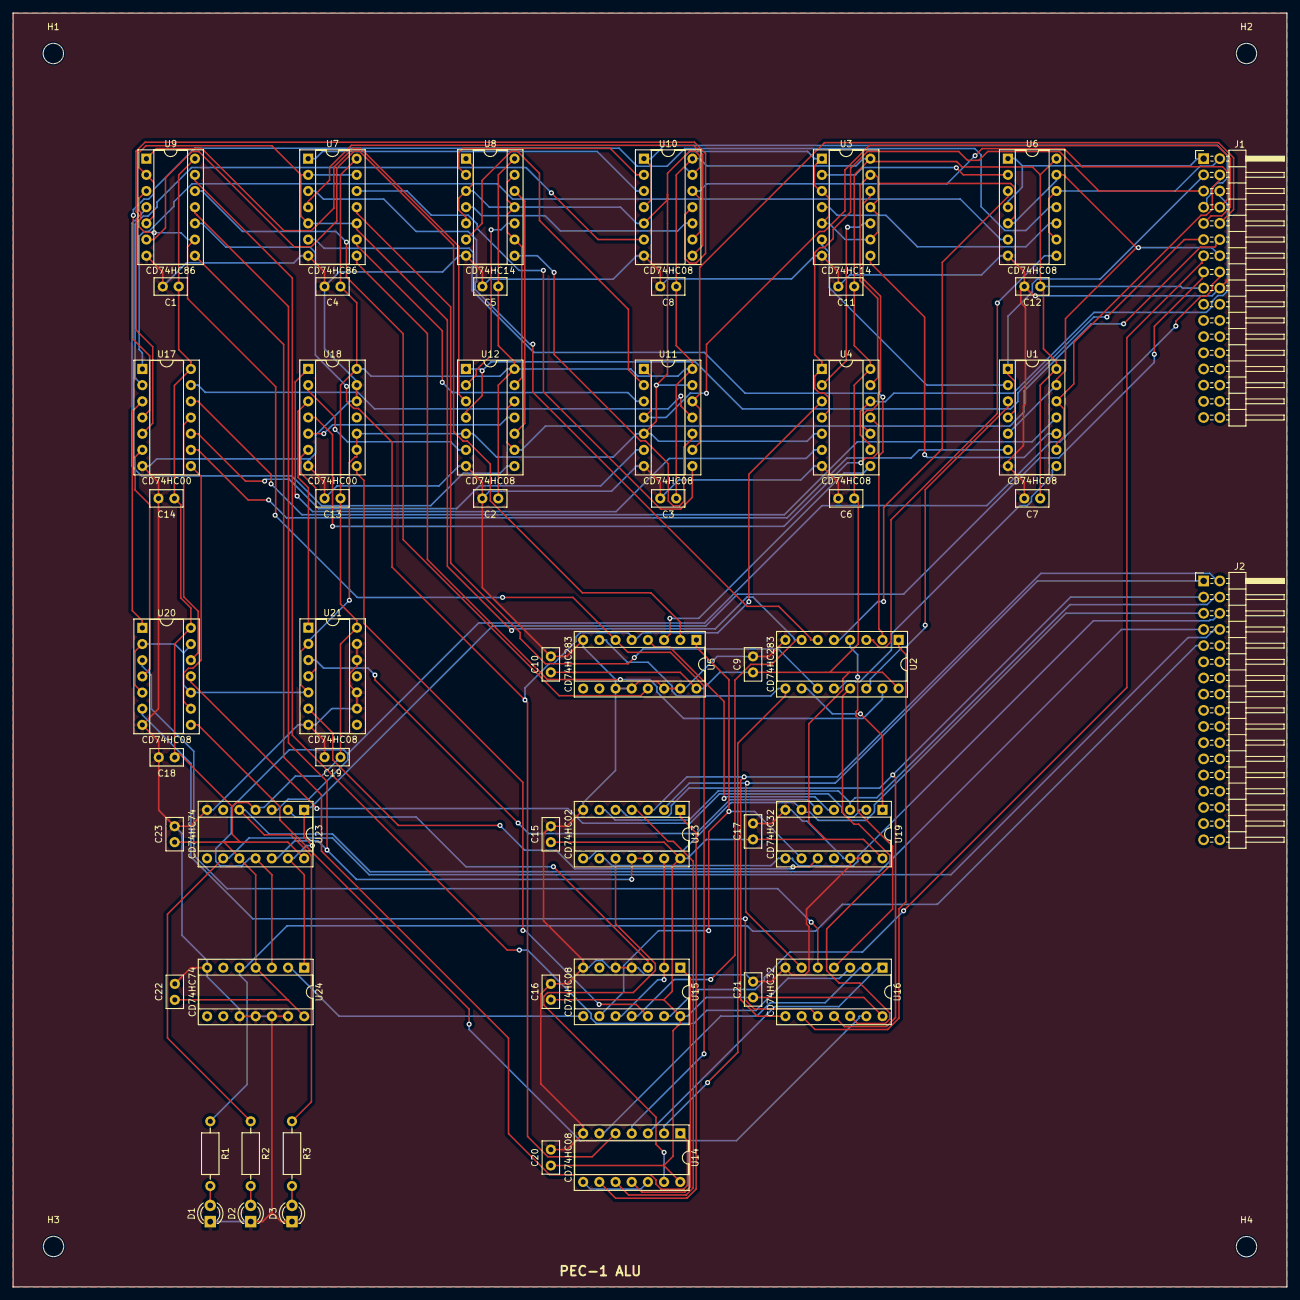
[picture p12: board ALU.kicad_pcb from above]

Board: 2 copper layers, 200.0 x 200.0 mm, 58 parts (0 on the bottom side), 107 nets.

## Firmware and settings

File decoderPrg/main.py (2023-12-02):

from machine import Pin
import time


oc3 = machine.Pin(1, machine.Pin.IN)
oc2 = machine.Pin(2, machine.Pin.IN)
oc1 = machine.Pin(3, machine.Pin.IN)
oc0 = machine.Pin(4, machine.Pin.IN)

ol3 = machine.Pin(5, machine.Pin.IN)
ol2 = machine.Pin(6, machine.Pin.IN)
ol1 = machine.Pin(7, machine.Pin.IN)
ol0 = machine.Pin(8, machine.Pin.IN)

zf = machine.Pin(9, machine.Pin.IN)
of = machine.Pin(10, machine.Pin.IN)
sf = machine.Pin(11, machine.Pin.IN)

sela2 = machine.Pin(14, machine.Pin.OUT)
sela1 = machine.Pin(13, machine.Pin.OUT)
sela0 = machine.Pin(12, machine.Pin.OUT)
selb2 = machine.Pin(17, machine.Pin.OUT)
selb1 = machine.Pin(16, machine.Pin.OUT)
selb0 = machine.Pin(15, machine.Pin.OUT)

ld0 = machine.Pin(18, machine.Pin.OUT)
ld1 = machine.Pin(19, machine.Pin.OUT)
ld2 = machine.Pin(20, machine.Pin.OUT)
ld3 = machine.Pin(21, machine.Pin.OUT)
ldo = machine.Pin(22, machine.Pin.OUT)
ldpc = machine.Pin(26, machine.Pin.OUT)

pm = machine.Pin(27, machine.Pin.OUT)
al = machine.Pin(28, machine.Pin.OUT)

oc = [0, 0, 0, 0]
ol = [0, 0, 0, 0]
flag = [0, 0, 0]

selector = [0, 0, 0, 0, 0, 0]
Load = [1, 1, 1, 1, 1, 1]


alithm = [0, 0]




mov1 = [0, 0, 1, 0]
mov2 = [0, 0, 1, 1]
add1 = [0, 1, 0, 0]
add2 = [0, 1, 0, 1]
sub1 = [0, 1, 1, 0]
sub2 = [0, 1, 1, 1]
nan1 = [1, 0, 0, 0]
nan2 = [1, 0, 0, 1]

jmp =  [0, 0, 0, 1]
jno =  [1, 0, 1, 1]
jze =  [1, 0, 1, 0]
jmi =  [1, 1, 0, 0]
jpl =  [1, 1, 0, 1]
inp =  [1, 1, 1, 0]
outp = [1, 1, 1, 1]
nop =  [0, 0, 0, 0]



def decoder (opeland):
    ret = [1, 1, 1, 1, 1, 1]
    
    if(opeland[0] == 0 and opeland[1] == 0):
        ret[0] = 0
        
    if(opeland[0] == 0 and opeland[1] == 1):
        ret[1] = 0
        
    if(opeland[0] == 1 and opeland[1] == 0):
        ret[2] = 0

    if(opeland[0] == 1 and opeland[1] == 1):
        ret[3] = 0
    
    return ret

while True:
    oc[0] = oc3.value()
    oc[1] = oc2.value()
    oc[2] = oc1.value()
    oc[3] = oc0.value()

    ol[0] = ol3.value()
    ol[1] = ol2.value()
    ol[2] = ol1.value()
    ol[3] = ol0.value()

    flag[0] = zf.value()
    flag[1] = of.value()
    flag[2] = sf.value()

    
    if oc == mov1:
        selector = [0, ol[2], ol[3], 1, 1, 0]
        Load = decoder(ol)
        alithm = [0, 0]
        print(oc)
        print(ol)
        print(flag)
        print("mov1")
        
    if oc == mov2:
        selector = [1, 0, 1, 1, 1, 0]
        Load = decoder(ol)
        alithm = [0, 0]
        print(oc)
        print(ol)
        print(flag)
        print("mov2")
        
    if oc == add1:
        selector = [0, ol[0], ol[1], 0, ol[2], ol[3]]
        Load = decoder(ol)
        alithm = [0, 0]
        print(oc)
        print(ol)
        print(flag)
        print("add1")
        
    if oc == add2:
        selector = [0, ol[0], ol[1], 1, 0, 1]
        Load = decoder(ol)
        alithm = [0, 0]
        print(oc)
        print(ol)
        print(flag)
        print("add2")
        
    if oc == sub1:
        selector = [0, ol[0], ol[1], 0, ol[2], ol[3]]
        Load = decoder(ol)
        alithm = [1, 0]
        print(oc)
        print(ol)
        print(flag)
        print("sub1")
        
    if oc == sub2:
        selector = [0, ol[0], ol[1], 1, 0, 1]
        Load = decoder(ol)
        alithm = [1, 0]
        print(oc)
        print(ol)
        print(flag)
        print("sub2")
        
    if oc == nan1:
        selector = [0, ol[0], ol[1], 0, ol[2], ol[3]]
        Load = decoder(ol)
        alithm = [0, 1]
        print(oc)
        print(ol)
        print(flag)
        print("nan1")
        
    if oc == nan2:
        selector = [0, ol[0], ol[1], 1, 0, 1]
        Load = decoder(ol)
        alithm = [0, 1]
        print(oc)
        print(ol)
        print(flag)
        print("nan2")
        
    if oc == jmp:
        selector = [1, 0, 1, 1, 1, 0]
        Load = [1, 1, 1, 1, 1, 0]
        alithm = [0, 0]
        print(oc)
        print(ol)
        print(flag)
        print("jmp")
        
    if oc == jno and flag[1] == 0:
        selector = [1, 0, 1, 1, 1, 0]
        Load = [1, 1, 1, 1, 1, 0]
        alithm = [0, 0]
        print(oc)
        print(ol)
        print(flag)
        print("jno")
        
    if oc == jze and flag[0] == 1:
        selector = [1, 0, 1, 1, 1, 0]
        Load = [1, 1, 1, 1, 1, 0]
        alithm = [0, 0]
        print(oc)
        print(ol)
        print(flag)
        print("jze")
    elif oc == jze and flag[0] == 0:
        selector = [1, 1, 0, 1, 1, 0]
        Load = [1, 1, 1, 1, 1, 1]
        alithm = [0, 0]
        
    if oc == jmi and flag[2] == 1:
        selector = [1, 0, 1, 1, 1, 0]
        Load = [1, 1, 1, 1, 1, 0]
        alithm = [0, 0]
        print(oc)
        print(ol)
        print(flag)
        print("jmi")
        
    if oc == jpl and flag[0] == 0 and flag[2] == 0:
        selector = [1, 0, 1, 1, 1, 0]
        Load = [1, 1, 1, 1, 1, 0]
        alithm = [0, 0]
        print(oc)
        print(ol)
        print(flag)
        print("jpl")
        
    if oc == inp:
        selector = [1, 0, 0, 1, 1, 0]
        Load = decoder(ol)
        alithm = [0, 0]
        print(oc)
        print(ol)
        print(flag)
        print("inp")
        
        
    if oc == outp:
        selector = [0, ol[0], ol[1], 1, 1, 0]
        Load = [1, 1, 1, 1, 0, 1]
        alithm = [0, 0]
        print(oc)
        print(ol)
        print(flag)
        print("outp")
        
    if oc == nop:
        selector = [1, 1, 0, 1, 1, 0]
        Load = [1, 1, 1, 1, 1, 1]
        alithm = [0, 0]
        print(oc)
        print(ol)
        print(flag)
        print("nop")
        
    #print(Load)
    
    sela2.value(selector[0])
    sela1.value(selector[1])
    sela0.value(selector[2])
    selb2.value(selector[3])
    selb1.value(selector[4])
    selb0.value(selector[5])
    
    ld0.value(Load[0])
    ld1.value(Load[1])
    ld2.value(Load[2])
    ld3.value(Load[3])
    ldo.value(Load[4])
    ldpc.value(Load[5])
    
    pm.value(alithm[0])
    al.value(alithm[1])
            
        

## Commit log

2023-11-12 Create README.md
    説明書いた
2023-11-12 Update README.md
    誤字修正
2023-11-12 Update README.md
    正式名称の追加
2023-11-12 Update README.md
    Architectureの追加
2023-11-27 Logisim用のシミュレータファイルの追加
2023-11-27 mainとtestのマージ
2023-12-02 デコーダプログラムの修正
